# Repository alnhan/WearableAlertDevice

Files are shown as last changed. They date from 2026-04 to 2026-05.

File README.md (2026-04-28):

# Senior Capstone Project: Wearable Alert Device
University of Oklahoma

School of Electrical and Computer Engineering

Semester: Spring 2026

<ins>Team Members:<ins>

Project Manager - Jonas Wollman

Hardware Engineer - Ryan Kiesau

Hardware Engineer - Cody Chan

Software Engineer - Alex Ho

README written by Alex Ho

# Overview
This repository contains all project files pertaining to the Wearable Alert Device project. The following information
provides guidance for setting up the software development environment as well as a general description of each
of the major components of the software.

# Table of Contents
1. [Downloading Arduino IDE](#downloading-arduino-ide)
2. [Initial Environment Setup](#initial-environment-setup)
   - [Arduino Nano ESP32 Board Package Installation](#arduino-nano-esp32-board-package-installation)
   - [Pin Numbering Setting Configuration](#pin-numbering-setting-configuration)
   - [Required Library Dependencies](#required-library-dependencies)
   - [Verifying and Uploading Code to a Microcontroller](#verifying-and-uploading-code-to-a-microcontroller)
4. [Software Development](#software-development)
   - [WearableAlertDevice.ino](#wearablealertdeviceino)
   - [config.h](#configh)
   - [WirelessDataTransmission.h/.cpp](#wirelessdatatransmissionhcpp)
   - [GunshotDetection.h/.cpp](#gunshotdetectionhcpp)

# Downloading Arduino IDE
For this Capstone project, the Arduino IDE was used as the software development environment.
The Arduino IDE can be downloaded [here](https://www.arduino.cc/en/software/). Ensure that 
some version of Arduino IDE 2.0 is downloaded, not the legacy Arduino IDE 1.0. 

Back to [Table of Contents](#table-of-contents)

# Initial Environment Setup
Once the Arduino IDE has been installed, some initial setup in its environment is needed before code can be correctly
uploaded into the Arduino Nano ESP32 microcontroller. There are three important parts to the setup: installing the Arduino
Nano ESP32 board package, setting the pin numbering to GPIO numbers, and installing library dependencies. 

Back to [Table of Contents](#table-of-contents)

## Arduino Nano ESP32 Board Package Installation
The first stage of the environment setup is installing the proper board package so that the environment can correctly compile
code and upload programs for Arduino Nano ESP32 microcontrollers. In the Arduino IDE, look on the left for the Boards Manager 
tab. Click on the Boards Manager tab to open it up.

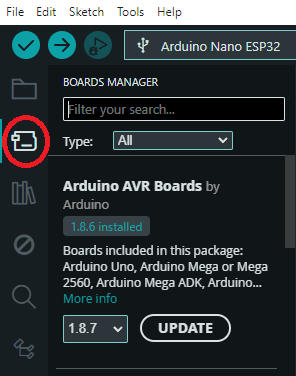
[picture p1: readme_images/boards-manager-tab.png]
Screenshot of Boards Manager tab in the Arduino IDE (circled in red).


Figure 1: Screenshot of Boards Manager tab in the Arduino IDE (circled in red).

In the search bar, type "Arduino ESP32 Boards." This package will contain the settings to recognize Arduino Nano ESP32
hardware. Select the Install button if the package is not already installed.

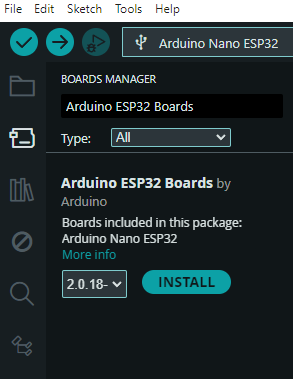
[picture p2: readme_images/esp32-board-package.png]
Screenshot of the Arduino ESP32 Boards package not installed yet.


Figure 2: Screenshot of the Arduino ESP32 Boards package not installed yet.

Once the package has been installed, the Arduino IDE will automatically install all the common software libraries associated with 
ESP32 microcontrollers, such as WiFi, Bluetooth, etc. No additional steps are needed to install these libraries.

Back to [Table of Contents](#table-of-contents)

## Pin Numbering Setting Configuration
The software developed for this project has been written specifically to use the Arduino Nano ESP32's GPIO numbers, not the 
standard Arduino pin numbers that are labeled on the physical device. **NOTE: IF THE PIN NUMBERING IS SET TO ARDUINO PIN NUMBERS 
INSTEAD OF GPIO NUMBERS, THERE WILL BE A GOOD CHANCE THAT INCORRECT PINS ON THE MICROCONTROLLER WILL BE USED BY THE SOFTWARE,
WHICH WILL MOST LIKELY PREVENT THE HARDWARE FROM FUNCTIONING PROPERLY.**

To change the pin numbering setting in the Arduino IDE, navigate to `Tools >> Pin Numbering` at the ribbon near the top of the IDE. 
In the `Pin Numbering` setting, there will be two options: `By Arduino pin (default)` and `By GPIO number (legacy)`. Set the `Pin Numbering`
setting to the `By GPIO number (legacy)` option.

Pin Numbering setting

Figure 3: Screenshot of Pin Numbering setting being set to the "By GPIO number (legacy)" option. The Pin Numbering setting can be 
found in the Tools tab in the ribbon near the top of the IDE.

Back to [Table of Contents](#table-of-contents)

## Required Library Dependencies
There are a few open-source libraries that the software relies on for its functionality. These external libraries are not automatically
installed by the Arduino IDE and will have to be installed manually. Below is a list of the open-source libraries:

1. [DFRobot_GNSS](https://github.com/DFRobot/DFRobot_GNSS) by DFRobot
2. [arduinoFFT](https://github.com/kosme/arduinoFFT) by kosme

The libraries can be downloaded by using the GitHub links above, or they can also be found in the `Software/dependencies` folder for
this project.

Once these libraries are downloaded, they need to be installed manually into the Arduino IDE. Navigate to `Sketch >> Include Library >> 
Add .ZIP Library...` at the ribbon near the top of the IDE. After clicking the `Add .ZIP Library` option, find the local `.zip` files 
of the libraries and add them to the Arduino IDE. 

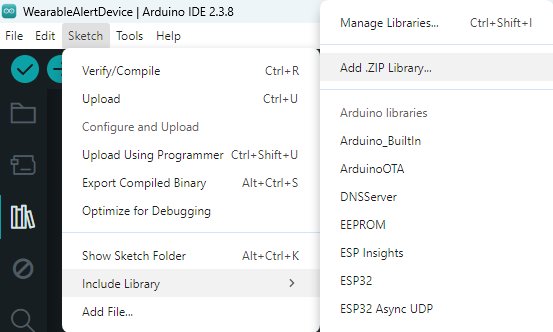
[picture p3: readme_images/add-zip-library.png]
Add .ZIP Library


Figure 4: Screenshot of the navigation to the "Add .ZIP Library..." option in the Arduino IDE.

Back to [Table of Contents](#table-of-contents)

## Verifying and Uploading Code to a Microcontroller
When connecting an Arduino Nano ESP32 microcontroller to the computer for the first time, it is possible that the Arduino IDE does not
recognize the hardware as an Arduino Nano ESP32 model specifically. Before verifying or uploading code to the microcontroller, first
navigate to `Tools >> Board`. Ensure that the board type says "Arduino Nano ESP32." If the board type does not say that, set the board
type to "Arduino Nano ESP32" by navigating to `Tools >> Board >> Arduino ESP32 Boards` and selecting "Arduino Nano ESP32."

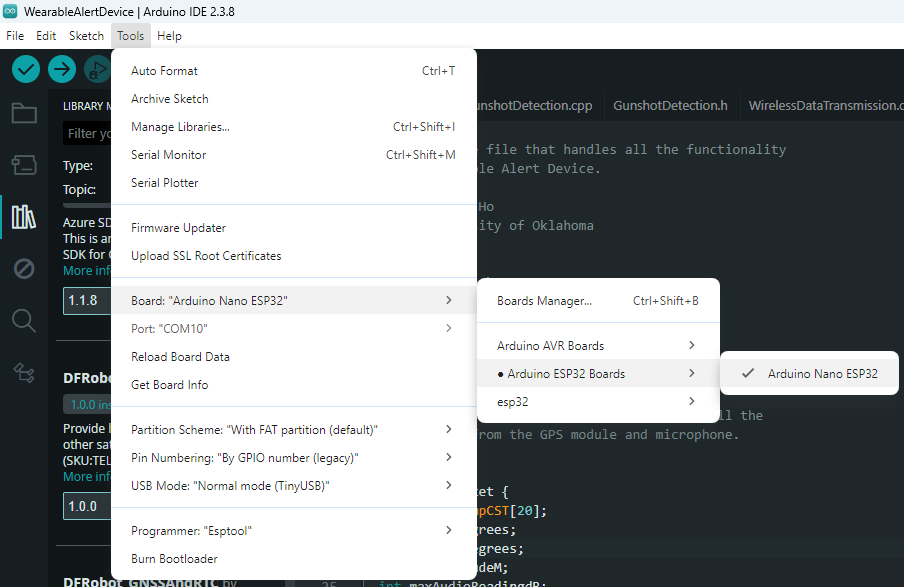
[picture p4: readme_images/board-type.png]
Selecting Board Type


Figure 5: Screenshot of the IDE's board type being set to "Arduino Nano ESP32."

To verify that the Arduino IDE properly recognizes the microcontroller as an Arduino Nano ESP32, connect the microcontroller to the
computer's USB-A port, and the IDE should display the COM port number and "Arduino Nano ESP32."

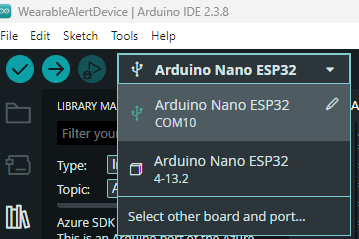
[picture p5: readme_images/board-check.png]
Checking Board Type


Figure 6: Example screenshot of the IDE detecting an Arduino Nano ESP32 on COM Port 10.

Once the IDE properly recognizes the Arduino Nano ESP32, code can now be properly installed on the hardware. There are two important
buttons in the IDE for installing software onto the microcontroller: the `Verify` button and `Upload` button. 

Verify and Upload Buttons

Figure 7: Screenshot of the `Verify` button (circled in red) and `Upload` button (circled in green) in the Arduino IDE.

The `Verify` button, identified by a checkmark symbol, compiles the code and ensures there are no compile errors. This button does not
upload the software into the microcontroller. The `Upload` button, identified by an arrow pointing right, performs the same function as 
the `Verify` button. However, once the code has been successfully compiled, the `Upload` button will then upload the software to the 
connected microcontroller. **For best practices, it is best to first press the `Verify` button before pressing `Upload` button when 
uploading new code to the microcontroller.**

# Software Development
The following section provides a general description of each of the software files. If further details are needed, comments and 
documentation can be found within the software files themselves. 

Back to [Table of Contents](#table-of-contents)

## WearableAlertDevice.ino
`WearableAlertDevice.ino` is the main software file for this project. This file serves as the device's main source for functionality.
The Arduino Nano ESP32 will look to this file for how to control the connected hardware. Functions and variables from supporting files 
such as `config.h`, `WirelessDataTransmission.h`, and `GunshotDetection.h` can also be used by `WearableAlertDevice.ino`. 

Back to [Table of Contents](#table-of-contents)

## config.h
`config.h` contains all the adjustable settings for the Wearable Alert Device. Instead of going into each of the different software
files to change certain settings, which can introduce potential bugs if not carefully done, these settings can be changed directly 
in `config.h`, and those changes will automatically propagate throughout the rest of software. As a result, changing a specific setting
for the Wearable Alert Device only requires changing a single value in `config.h`, and developers do not need to parse through all the
complex code to change each instance of the setting that appears in the code.

Back to [Table of Contents](#table-of-contents)

## WirelessDataTransmission.h/.cpp
`WirelessDataTransmission.h` handles the software that wirelessly transmits the data from the Wearable Alert Device to a mobile app.
For this project, Bluetooth Low-Energy was used as the protocol for transmitting data wirelessly. Thus, `WirelessDataTransmission.h`
contains the software that initializes the microcontroller's Bluetooth Low-Energy module and handles when a mobile device connects
or disconnects from the Wearable Alert Device. 

Back to [Table of Contents](#table-of-contents)

## GunshotDetection.h/.cpp
`GunshotDetection.h` handles the audio sampling and processing needed to detect a gunshot. This file creates all the necessary
buffers that store audio samples collected by the microphone. In addition, the file also performs the mathematical conversions
needed to convert the analog voltage from the microphone into a fairly accurate dB Sound Pressure Level reading. What is 
important to note about `GunshotDetection.h` is that it includes the previously-mentioned `arduinoFFT` library, allowing 
`WearableAlertDevice.ino` to use `arduinoFFT`'s frequency conversion and analysis functions. 

Back to [Table of Contents](#table-of-contents)

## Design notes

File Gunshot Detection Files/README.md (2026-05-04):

# Microphone Information
Microphone files for the OU Capstone Wearable Alert Device project. <br>
Schematics and Datasheets

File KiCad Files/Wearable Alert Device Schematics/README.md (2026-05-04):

# Contains all schematics related to the whole Wearable Alert Device
Both the GPS feature and the microphone feature are included in the schematics.

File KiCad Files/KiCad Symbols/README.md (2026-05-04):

# Kiad Symbols related to the Wearable Alert Device

CCEW Wearable Alert Device: All symbols related to the Gunshot Detection
Arduino Nano ESP32, I2S MEMS Microphone, Boost Converter, and Button

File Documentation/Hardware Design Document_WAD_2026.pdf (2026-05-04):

## Wearable Alert Device: Hardware Design Document

University of Oklahoma
School of Electrical and Computer Engineering Spring 2026 Semester
Senior Capstone Project

Team Members:
Jonas Wollman - Project Manager Ryan Kiesau - Hardware Engineer Cody Chan - Hardware Engineer Alex Ho - Software Engineer

Written By:
Cody Chan
Ryan Kiesau

## Table of Contents

Overview | 2
Power Supply | 3
Micro-Lipo Charger | 4
Position Module | 5
Analog Microphone | 6
Arduino Nano Esp32 | 7
Testing LED | 8
Boost Converter | 9
Hardware Documentation | 11
Block Diagram | 11
Schematics | 13

Overview
This hardware design document describes the various hardware components used in the

building and testing of the CCEW WAD capstone project. This document will list all hardware

developments including listings on all parts/chips used in the design of the WAD, Block

diagrams of the WAD, Schematics of the WAD, and the final PCB design that was not

implemented but planned for.

The WAD’s mission is to create a discrete device that could be worn in case of

emergency assistance. The overall goal of the WAD is to alert authorities on location, elevation,

and an immediate threat such as a gunshot.

The intended audience that we are building the device for is not that of first responders.

Instead we are thinking about secondary responders who may not have field training but may

still be in dangerous scenarios while working. This device is made for them to have a way of

contacting authorities while not giving too much information to the potential assailant.

Power Supply

Description:

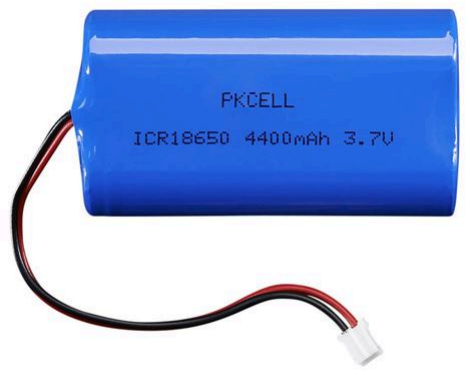
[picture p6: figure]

A lithium-ion battery pack made of two 2200mAh cells totaling to 4400mAh operating at 3.7V

Specifications:
Parameters: | Values
Lithium-ion Cells | 2 x 2200mAh
Max Recommended Charging Rate | 1A
Max Recommended Discharging Rate | 2.2A

Role in this system:

This battery pack is the main source of power for the device. Connected with a JST 2-pin cable, the pack is compatible with any JST or similar connector.

Why was this component chosen:

This battery pack was chosen as it provides more than enough amperage to cover all components operating within the device. Its milliampere-hours can power the device for an extended amount of time before needing to recharge. This battery pack is also compatible with the device’s chosen charging component while non-Adafruit batteries are not.

Micro-Lipo Charger

Description:

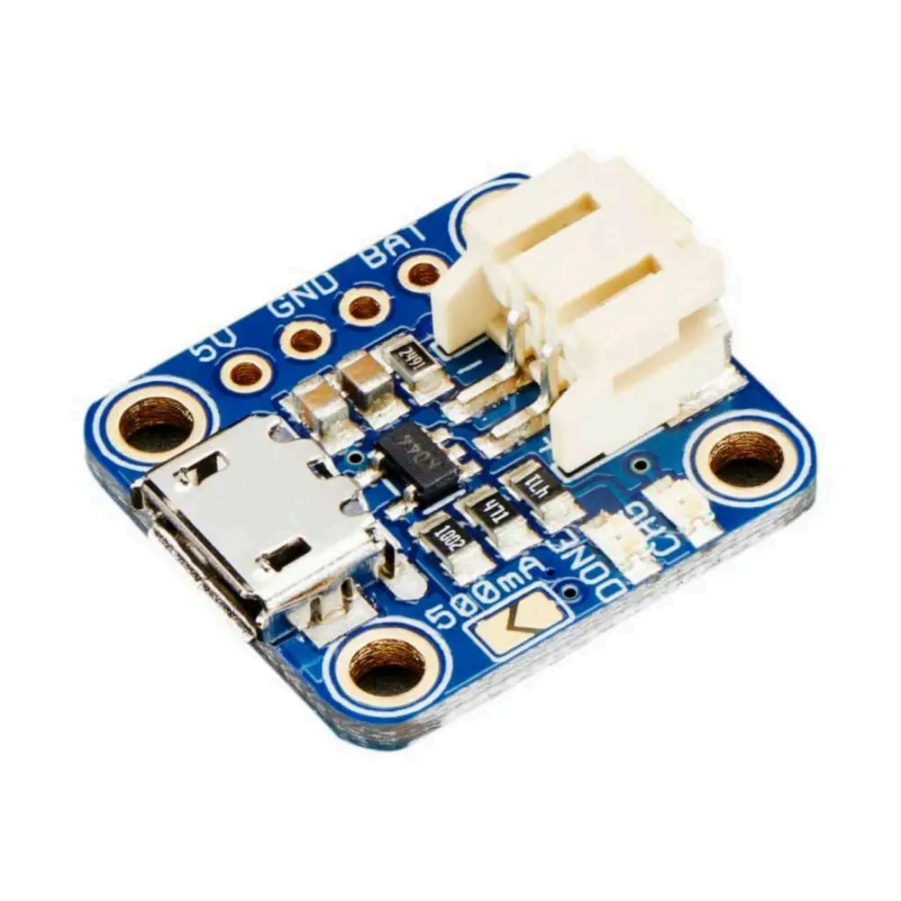
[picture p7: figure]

A small Lipo charger able to recharge any 3.7/4.2V lithium polymer or lithium ion rechargeable battery by a JST plug through a Micro-B USB. A red LED will be active when charging and a green LED will be active once charging is complete.

Specifications:
Parameters: | Values
Recommended Batteries | Rechargeable 3.7/4.2V LiPoly/LiIon Batteries (Adafruit Only)
Micro-B USB Connector Voltage | 5V
Charge Current | 100mA, Adjustable to 500mA

Role in this system:

The Lipo-Charger regulates the charging process using a constant current, prevents overcharging, and protects the battery. Due to the dual functionality of the USB and JST ports, it allows the device to be recharged without disconnecting the battery, offering continuous operation and usability.

Why this component was chosen:

The Micro-Lipo Charger was chosen mainly for its compatibility with the battery pack. It allows the user to be able to charge the device without needing to disconnect the battery. The charger also handles all battery protection independently of the microcontroller without external components, improving safety and reliability. Additionally, the charge current can be changed between 100mA and 500mA or be fully customizable with a single resistor on the PROG pin

Position Module

Description:

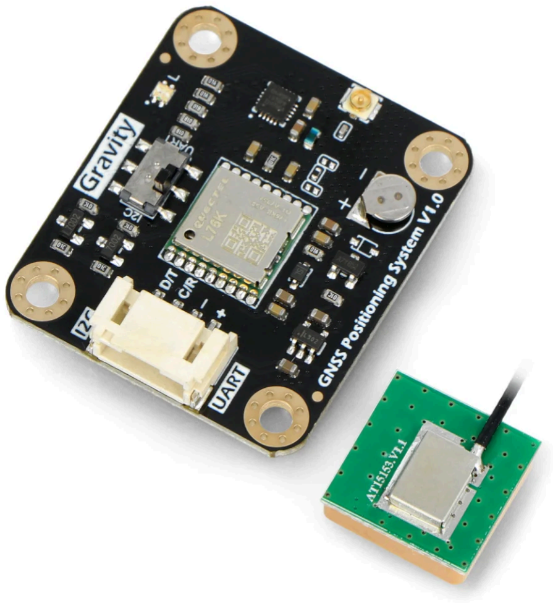
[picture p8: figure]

The Gravity: Receiver Module is a joint positioning mutli-satellite device that provides high-precision, high-speed, and stable data readings of longitude, latitude, altitude, and time.

Specifications:
Parameters: | Values
Operating Voltage | 3.3-5.5V DC
Output Signal | I2C/UART
Power Consumption | 40mA
Positioning Time | 30s-Cold Start; 2s-Hot Start
Antenna Interface | IPEX1
Antenna Frequency | 1561-1575.42MHz +/- 3MHz

Role in this system:

The receiver module is responsible for determining the device’s real-time geographical location. It receives signals from multiple satellite constellations and computes position data. This information is sent to the microcontroller where it’s constantly updated until an alert is activated and sends out the most recent data to the app for emergency services.

Why this component was chosen:

This module was chosen because it supports multiple satellite constellations, which improves accuracy and reliability in multiple environments. The module offers two-meter accuracy and quick positioning updates, which is critical for emergency response applications. Altitude is given alongside time and coordinates, which some smartphone maps do not offer or have the information split between different apps. Additionally, the module supports I2C, allowing for simple integration for the microcontroller and reduces wire complexity.

Analog Microphone

Description:

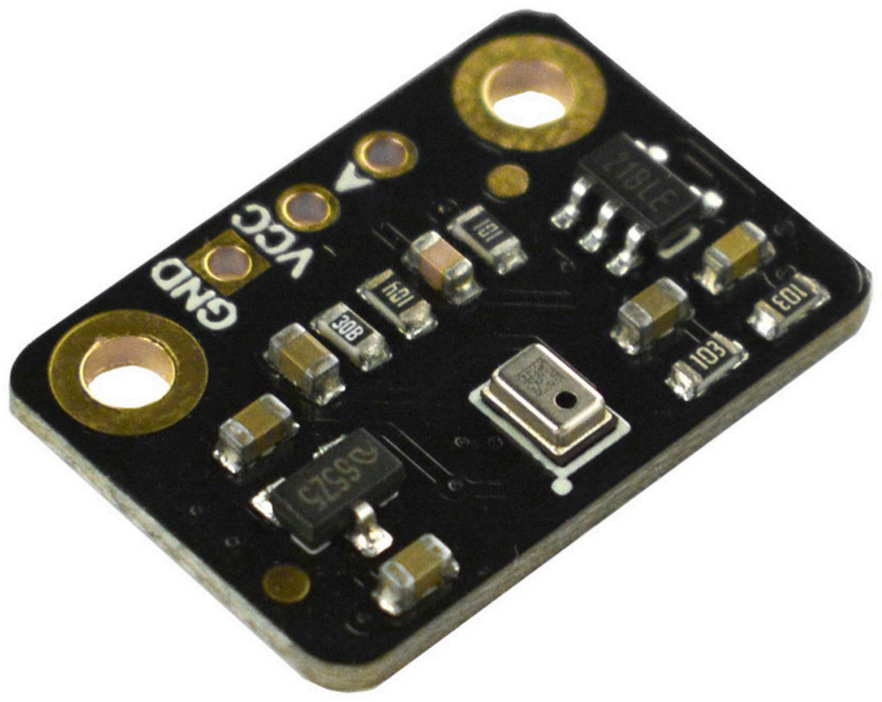
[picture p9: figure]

The Fermion MEMS Microphone is an compact analog microphone built on a Micro-Electro-Mechanical System (MEMS).

Specifications:

Parameters: | Values
Operating Voltage | 3.3V DC
Direction | Omnidirectional
Output Type | Analog
Maximum Sound Pressure Level | 110 dB
Signal to Noise Ratio | 59 dB

Role in this system:

This microphone is the main source where soundwaves are read and analyzed. It constantly monitors the environment and produces an analog voltage that will be sent via the amplitude of incoming sounds. This signal will be converted and passed through an ADC GPIO pin on the Arduino Nano ESP32, where it is sampled in the software. This microphone does not perform any type of action or decision-making on its own. The microphone’s purpose is to read in the data for the software to read and interpret. In this case, it will read in any type of noise, ranging from “quiet” to a gunshot.

Why this component chosen:

The Fermion MEMS Microphone was chosen based on a misordering issue. Originally, the plan was to use the Fermion I2S MEMS Microphone, which is a digital microphone able to read up to 140 dB. However, there was an ordering issue, and the wrong component came in. The digital microphone would have been using I2S and would have reduced a lot of unnecessary noise; however, the Fermion MEMS Microphone still functions as needed. The MEMS Microphone is directly connected to the ESP32’s ADC and has no protocol, meaning no clock or synchronization is needed, making the firmware simpler. The max 110 dB also allows the device to read in all types of loud sounds without damaging the microphone sensors, even if clipping were to occur.

Wiring to the Arduino Nano ESP32:

VCC | 3.3V
GND | GND | Shared GND for Device
Aout | DC GPIO Pin | Analog Audio

A 0.1 uF decoupling capacitor should be placed between the VCC and GND pins of the microphone. This filters out the noise the analog microphone produces before audio sampling.

Arduino Nano Esp32

Description:

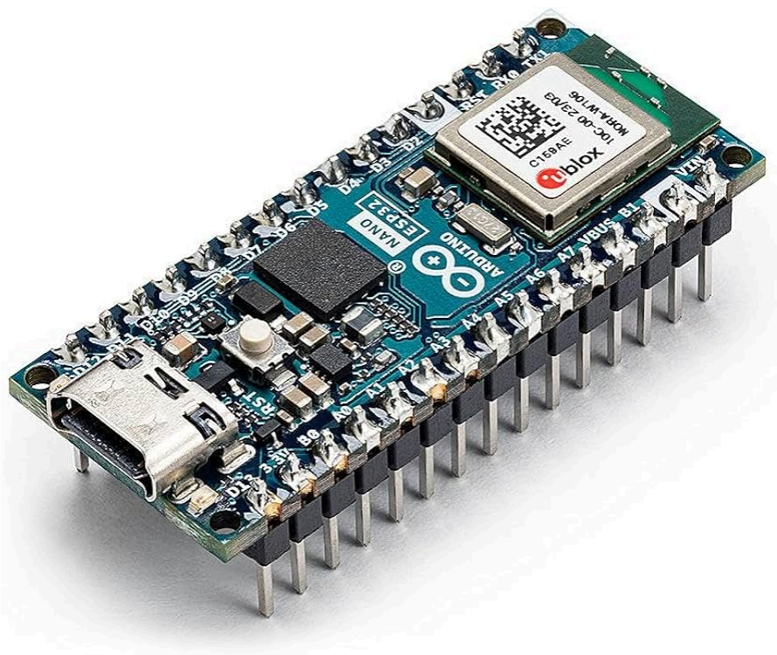
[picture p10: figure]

The Arduino Nano ESP32 is built around the r-block NORA-W106 module that has capabilities of Wi-Fi and Bluetooth 5.0 functions in a small form factor. This microprocessor will be considered as the brain that will collect the audio from the microphone, run through the firmware, collect GPS data, and transmit an emergency response via Bluetooth. This Arduino

Nano ESP32 can be powered by a USB-C built on the board but this product will be powered by a 3.7V Li-ion battery, running on an operating voltage of 3.3V.

Specifications:

Parameters: | Values
Operating Voltage | 3.3V
Bluetooth | Bluetooth 5.0 (Blue Energy)
GPIO | Multiple digital and analog I/O pins
Form | Arduino Nano

Role in the System:

The Arduino Nano ESP32 will serve as the brain of the gunshot-detection and GPS module. When working with the microphone, it will continuously sample voltage data from the microphone output at a defined sampling rate. Each sample will be stored for processing. There will be a Hamming window and the Fast Fourier Transform that will be during this analysis. When the characteristics are met (the threshold), the firmware will send a signal in the event of a gunshot and trigger an alert response. For the button, it will be connected to a GPIO pin to act as an emergency button, regardless of the microphone detection. Upon detection or a button press, the ESP32 will send a signal via Bluetooth to alert responders. The LED connected to the GPIO pin is for testing purposes only, and whenever a detection happens or a button is pressed, it will send a visual instead of looking at the phone.

Why was this component chosen:

The Arduino Nano ESP32 was chosen because it had all the features needed for our product to function. It was sufficient enough to perform Bluetooth communication, processing, and hardware integration.

Testing LED
Description:

The testing LED is a standard red LED used for development and validation assistance. The LED is also used to turn on if there is a gunshot detected or if the button is pressed to signal to the user discreetly that a signal has been sent. This LED will be incorporated into the final product, but it will not be a part of the interface for the user to use. For this product, it is made to be as discreet as possible, so having an LED turn on in the field would potentially alert the perpetrators.

Specifications:

Parameters: | Values
Type | Red LED
Forward Voltage | ~2.0V – 3.3V LED (2V for Red)
Current Limiting Resistor | 1k Ohm
Control Type | Digital GPIO Pin

Role in the System:

The LED is connected to the GPIO output on the Arduino Nano ESP32. In the firmware, whenever a gunshot is detected or if the button is pressed, it will send an alert via Bluetooth to the phone to send a signal. During the testing phase, like loud clapping and gunshot, the LED turns on. This allows us to know whether a signal was sent or not and to validate the performance without waiting for the notification on a phone.

Connections:

LED Anode (+) | To a resistor, current limiting, to GPIO Pin
LED Cathode (-) | Directly to GND

Boost Converter

Description:

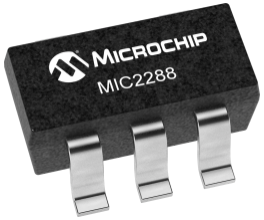
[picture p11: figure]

The MIC2288 is a 1.2MHz PWM, DC/DC boost switching regulator. It implements a constant frequency current-control scheme designed for high-efficiency power conversion.

Specifications:
Parameters: | Values
Input Voltage | 2.5-10V
Output Voltage | Adjustable to 34V
PWM Operation | 1.2MHz
Switch Current | Over 1A

Role in the system:

The MIC2288 Boost Converter steps up the battery voltage from 3.7V to 5V required by the microcontroller. It provides a stable supply voltage to the microcontroller, even as the battery voltage drops during discharge.

Why this component was chosen:

The MIC2288 was chosen as it’s a compact and efficient boost converter that requires few external components, making it ideal for tight-spaced designs. It can provide a 5V output from a low-voltage battery while maintaining efficiency, maximizing battery life. Since the component is adjustable to 34V, this makes it easy to modify if the output voltage needs to be changed.

NOTE: The MIC2288 is not included within the final design of the device nor the schematic. Multiple voltages and external component values were tested, but the output voltage ripple was too much for the Arduino Nano ESP32 to handle such that the Bluetooth feature was not operational. Luckily, the entire device works perfectly when powered directly from the 3.7V battery into the microcontroller’s VIN pin.

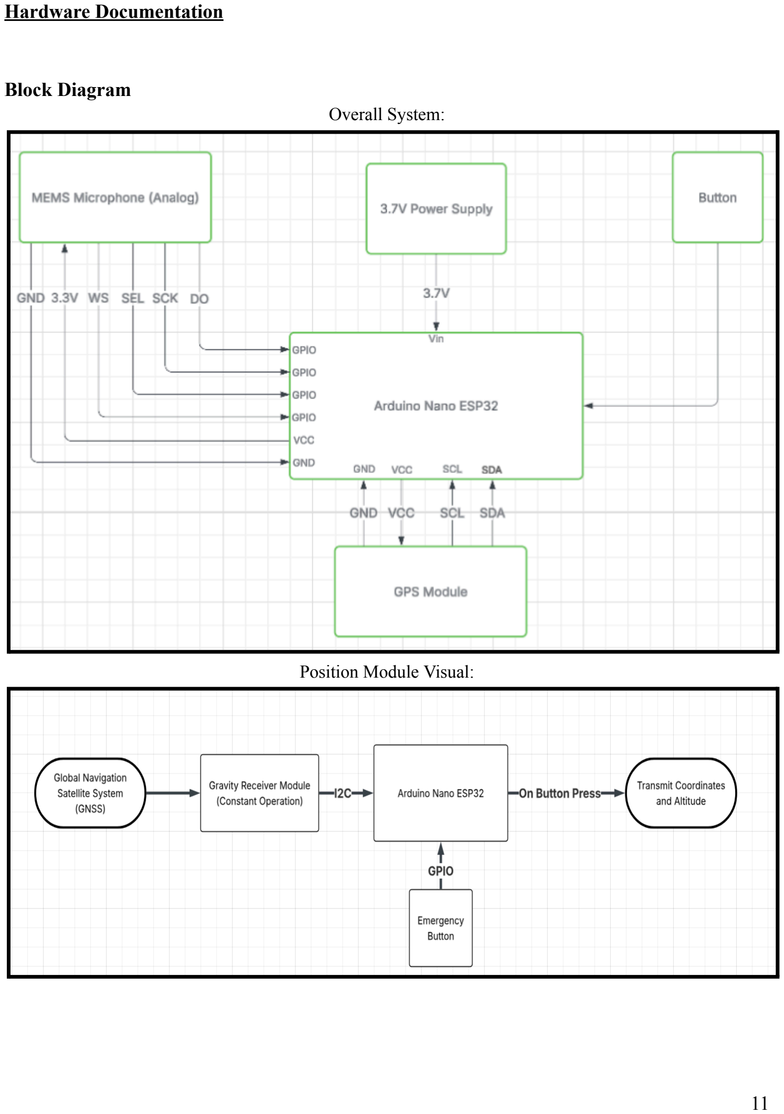
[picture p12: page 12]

Hardware Documentation

Block Diagram
Overall System:

Position Module Visual:

Microphone Visual:

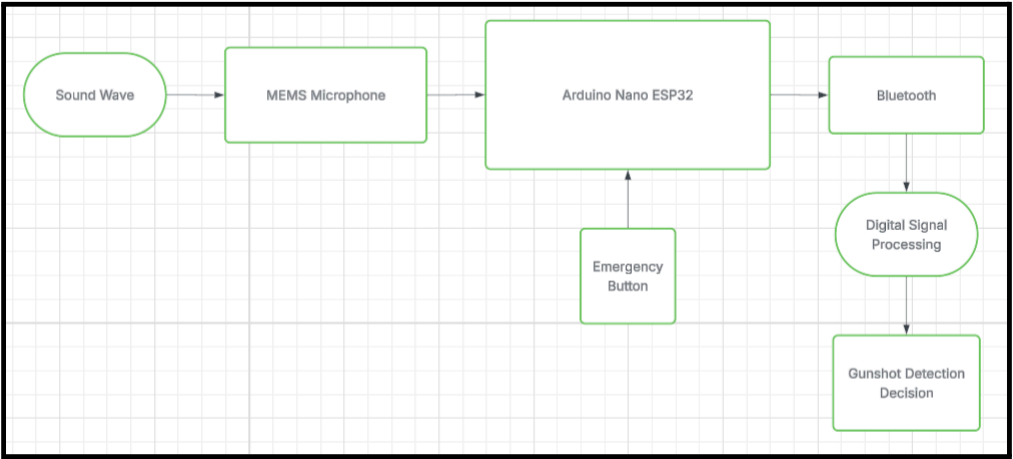
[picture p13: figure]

Schematics

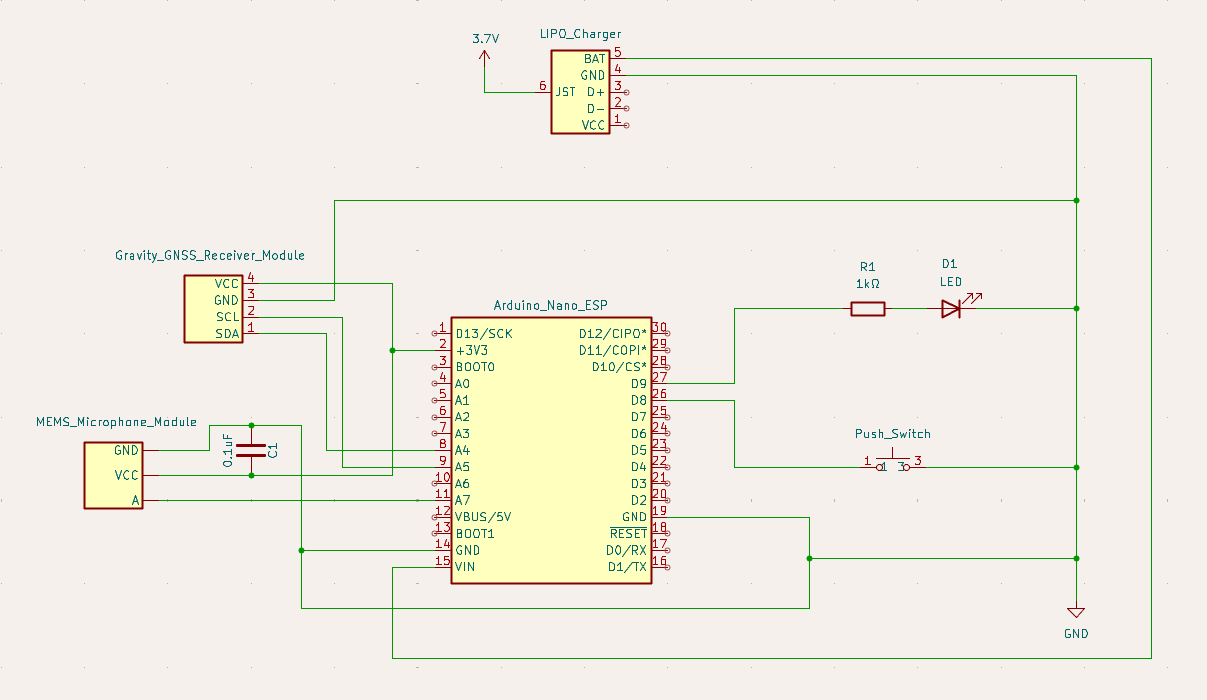
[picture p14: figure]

Starting with the microphone, the VCC is connected to the 3.3V rail of the Arduino Nano ESP32. The analog pin of the microphone is connected to pin A7 of the ESP32. Between the GND and the VCC of the microphone, there is a decoupling capacitor of 0.1uF to limit the noise from the analog microphone. Next with the Gravity: GNSS Receiver Module (GPS Module), the VCC is connected to the same 3.3V rail of the ESP32, the SCL is connected to A5 of the ESP32 because the pin has SCL capabilities, and the SDA is connected to A4 of the ESP32 because the pin has SDA capabilities. The 3.7V is connected to the Micro Lipo Charger via a JST connector and then the Micro-Lipo Charger’s BAT is connected to the Vin of the ESP32. The testing LED’s anode is connected to a limiting resistor to pin D9 of the ESP32 and the cathode is connected to GND. The push switch pin 1 is connected to pin D8 of the ESP32 and pin 3 of the push button is connected to GND. All GND from all the components in this circuit connects to the common GND.

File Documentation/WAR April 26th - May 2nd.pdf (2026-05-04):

Executive Summary: For our last week the team finished everything. Our documentation on

both the hardware and software side has been completed and the additional documentation has

been completed and committed to the github. This week we also finished our Final demo

presentation and practiced it multiple times in order to get a better understanding for our final

presentation in person on Monday 5/4. The team also created a case for the WAD and although

they ran into issues with the initial design they were able to get a working usable case on the

WAD. Our team is ready and waiting to give our final presentation at which point all

documentation will be handed over in the form of the presentation folders and the USB archives.

Task / Time Take / Completed Y/N
Hardware:

Cody C.
Progress:
- 4/26 –
- Work on Presentation Slides (~1 Hours)

■ Changes made to the project:

■ I2S Microphone to MEMS Microphone

■ Everything is the same, omnidirectional, 59dB Noise to

sound ratio

■ Main difference is the Sound Pressure Level (140dB vs

110dB)

■ Future Planning:

■ Smaller form factor

■ PCB implementation

■ High Decibel Microphone

- Calculated Run time for Wearable Alert Device
- Edit GitHub (~20 Minutes)
- 4/29 –
- Team meeting (~2 Hours 30 Minutes)

■ Field data collection for GPS module

■ Talk about plans for Final Demonstration

■ Practiced Final Presentation

- Update Symbol for Micro-Lipo Charger (~5 Minutes)
- Update Schematics and Wiring Diagram (~5 Minutes)
- Work on Hardware Design Document (~3 Hours)

■ Create descriptions for Arduino Nano ESP32, LED, and MEMS

Microphone

■ Upload Schematics

■ Upload Block Diagrams

■ Visual of Microphone

■ Whole Black Diagram

- Update GitHub (~10 Minutes)
- 5/2 –
- Team Practice (~30 Minutes)

Total Hours Worked: ~ 7 Hours 40 Minutes

Future Work/Plan

- 5/4 - Final Demonstration at 5:30 pm

Task / Time Take / Completed Y/N
Hardware:

Ryan K.
Progress:
- 4/27 - Presentation Slides (~1hr 30min)
- Worked on our Final Demo Presentation Slides for the upcoming team meeting
- 4/29 - Team Meeting/Presentation Practice (~2hr 30min)
- Met with team to talk about upcoming needs with documentation
- Gathered GPS data and made final edits to Final Demo Slides
- Practiced the Final Demo with the team
- 4/29 - Documentation (~1hr 45min)
- Started writing the Hardware Design Document

■ Filled out and gathered information for the battery and Micro-Lipo

Charger

- 5/1 - Documentation (~1hr 30min)
- Continued filling out the Hardware Design Document

■ Filled out and gathered information for the positioning module, and the

boost converter

- 5/2 - Finalize Documentation (~20min)
- Formatted and reviewed the Hardware Design Document and made minor edits

where needed

Total Hours Worked: ~7hr 35min

Future Work/Plan:

- Present our Final Demo on 5/4 @ 5:20pm

Task / Time Take / Completed Y/N
Software:

Alex H.
Progress:
- 4/27 (3 h 52 min)
- Created two gunshot detection videos for the Final Demo presentation, showing

off results.

- Computed accuracy of WAD for each gunshot detection video.
- Shared video format with the team to receive their approval and feedback.
- Inserted gunshot detection videos into the Final Demo presentation.
- 4/28 (1 h 41 min)
- Formatted appendix and gunshot detection slides for the Final Demo presentation.
- 4/29 (2 h 21 min)
- Worked with the team to obtain some new GPS tracking data to present at the

Final Demo.

- Obtained coordinates and altitude of the OU Engineering Quad fountain.

Compared this data from the WAD with data from Google Maps and an

altitude app.

- Practiced Final Demo presentation with the team.
- 5/1 ( 5 h 37 min)

- Finished the user manual for the Wearable Alert Device. Added images and steps

for installing the nRF Connect app, as well as writing brief descriptions of each of

the device’s features.

- 5/2 (39 min)
- Ran more practices with the team on the Final Demo presentation.
- Discussed plans to merge the GitHub repository so that all project files are

together.

- Added slight modifications to the Final Demo presentation.
- 5/3 (44 min)
- Double-checked that the README file, user manual, and code are all uploaded to

the GitHub repository in their final versions.

- Merged all branches in the GitHub repository to compile all project files together.

Total Hours Worked: 14 h 54 min

Future Work/Plan:

- Present project at the Final Demo presentation on Monday 5/4

Project Manager:

Jonas W.
Progress:
- 4/28 Finish my portion of final slides (1 Hours)
- Create and finish my final budget slides and introduction slide
- 4/29 Team meeting (~2 Hours 30 Minutes)
- Test the Position Module
- Test the bluetooth range

- 4/30 Create the WAD Case (3 Hours)
- Create the STL and Obj Files of the WAD Device’s case
- Upload to the GIT
- 5/1 Send the Case to volunteer 3D printer (1 Hours)
- Coordinate with the volunteer on the printing of the Case
- Plan on pick up/drop off of case
- 5/3 Finish Documentation(2 Hours)
- Finished the Final budget/BOM
- Finished formatting of the HDD and the User Manual
- Upload everything to GitHub
- 5/3 Build Case (1 Hours)
- Got the case parts and finished assembling, ran into the issue of the device on the

inside being a bit too long but we found a solution by adding lots of tape.

Total Hours Worked: 10 Hours 30 Minutes

Future Work/Plan:

Print and create the final demo folders

Format the USB archives

Present the final Demo!

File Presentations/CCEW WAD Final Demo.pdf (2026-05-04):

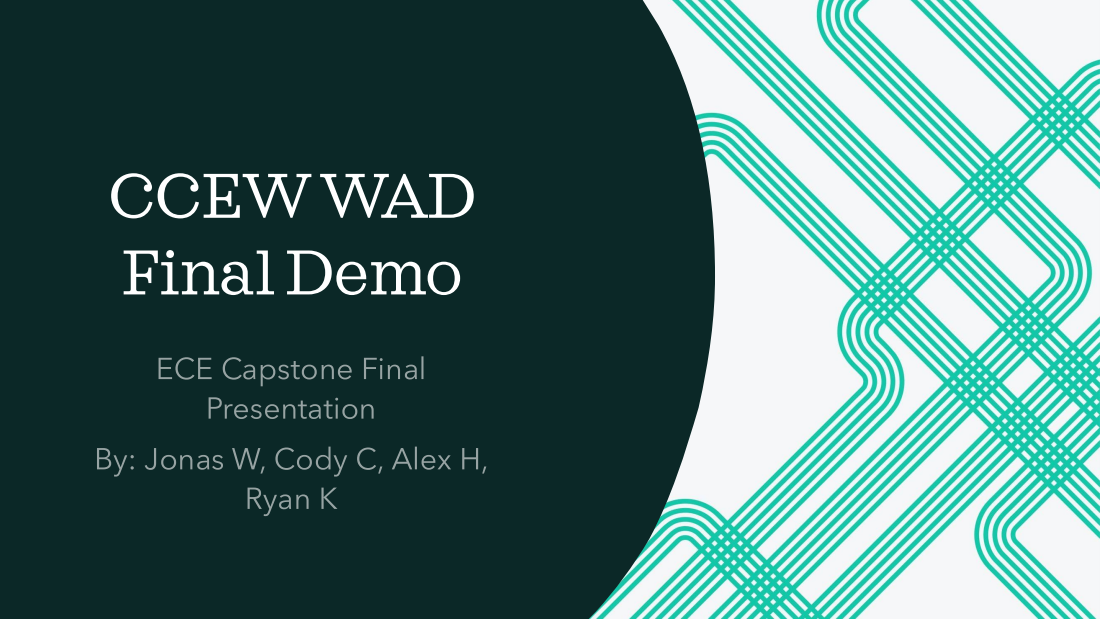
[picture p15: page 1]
CCEW WAD Final Demo

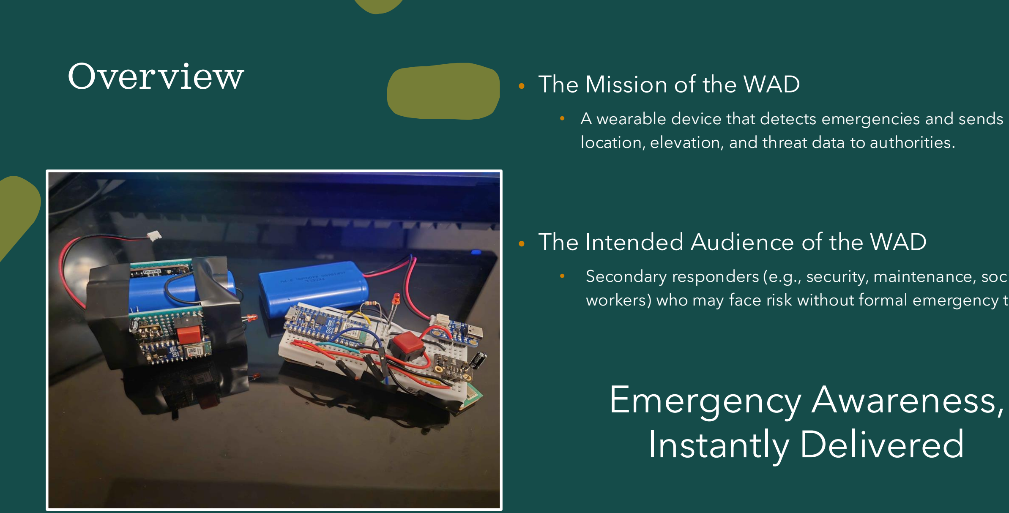
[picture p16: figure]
Overview; • The Mission of the WAD; • The Intended Audience of the WAD; Emergency Awareness, Instantly Delivered

- A wearable device that detects emergencies and sends real-time location, elevation, and threat data to authorities.
- Secondary responders (e.g., security, maintenance, social workers) who may face risk without formal emergency training.

JW

# Specific Features

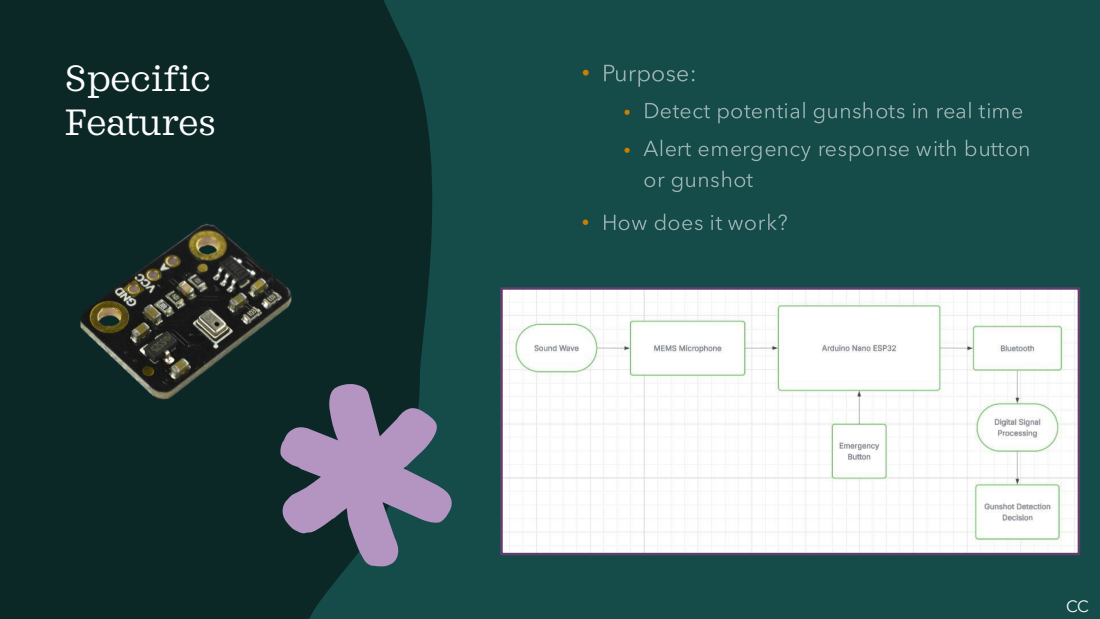
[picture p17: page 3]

# Specific Features Con't

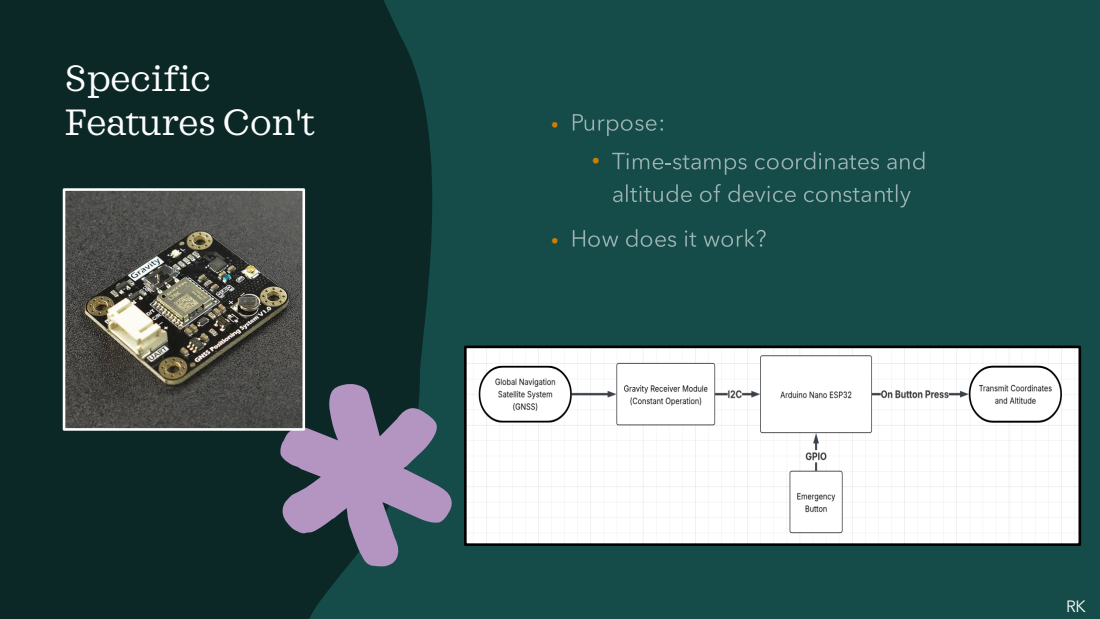
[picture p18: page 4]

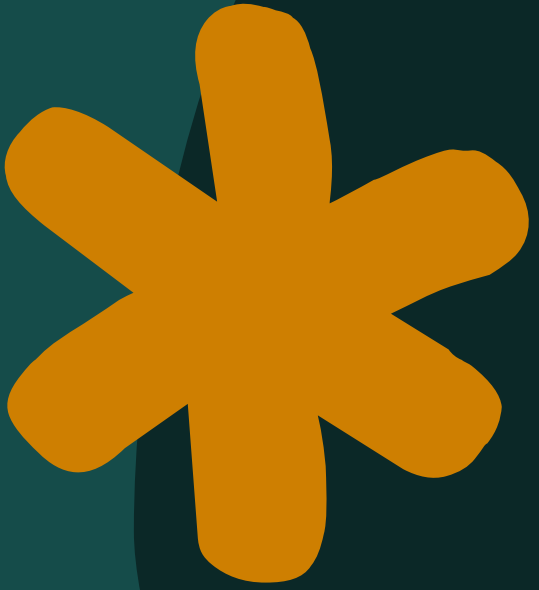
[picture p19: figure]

# Changes Made in Project

CC/
RK

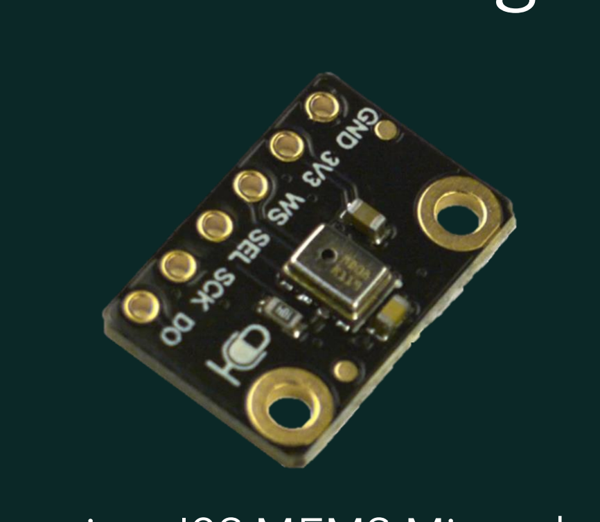
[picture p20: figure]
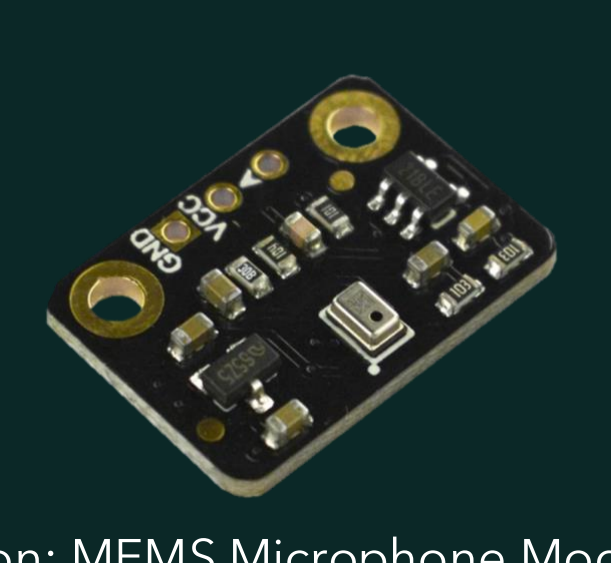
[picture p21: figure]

Fermion: I2S MEMS Microphone | Fermion: MEMS Microphone Module

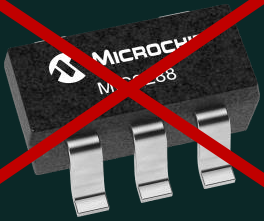
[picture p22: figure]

## Testing and Demonstration: Button and Wireless Data Transmission

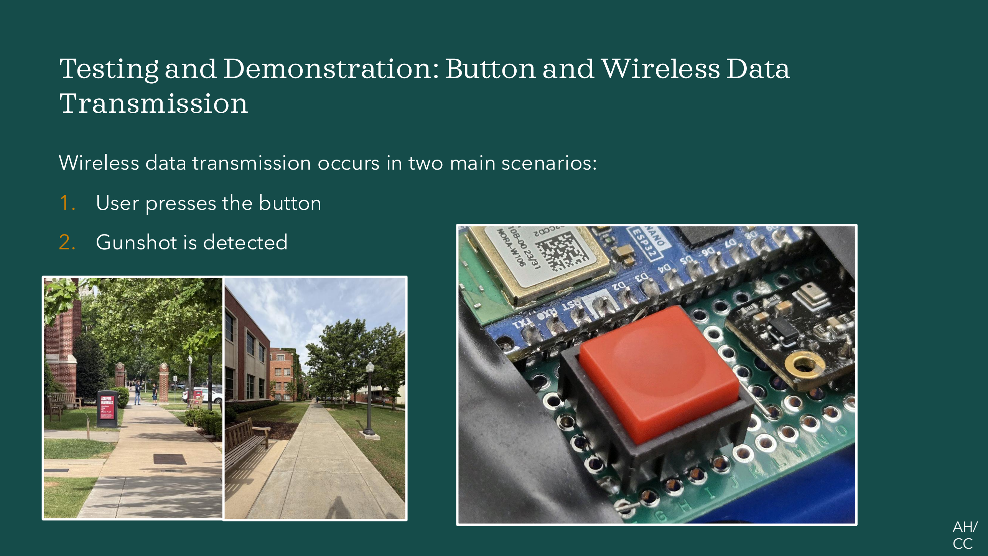
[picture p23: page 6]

Wireless data transmission occurs in two main scenarios:

1. User presses the button
2. Gunshot is detected

AH/
CC

## Testing and Demonstration: GPS Module

AH/
RK

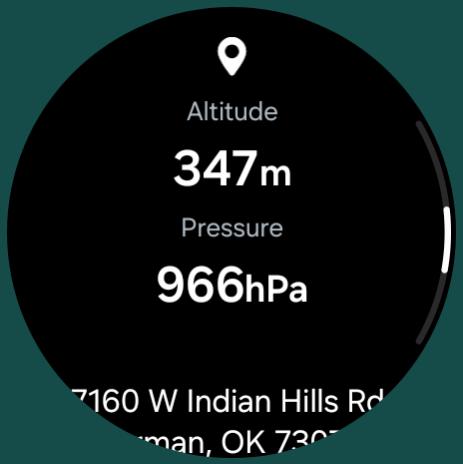
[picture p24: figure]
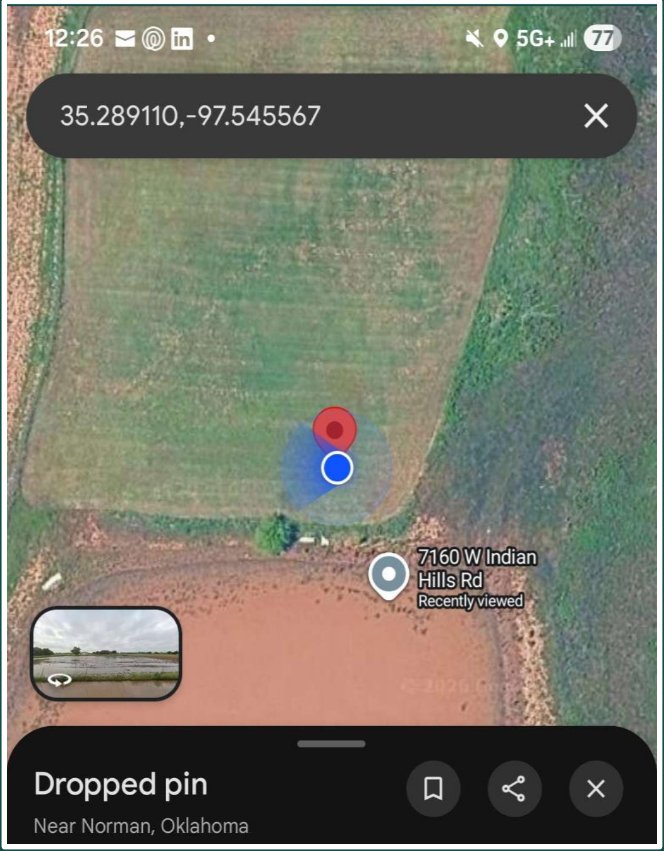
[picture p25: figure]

Mobile App Data | Value
Timestamp (CST) | 4/24/2026 12:26:38 PM
Latitude (Degrees) | 35.28901˚
Longitude (Degrees) | -97.54530˚
Altitude (Meters) | 345.69 m

Location: Farm

Percent Differences:
(calculations in Appendix C)

Latitude: ~2.8 ∗ 10⁻⁴ %

Longitude: ~2.7 ∗ 10⁻⁴ %

Altitude: ~0.378 %

## Testing and Demonstration: GPS Module

AH/
RK

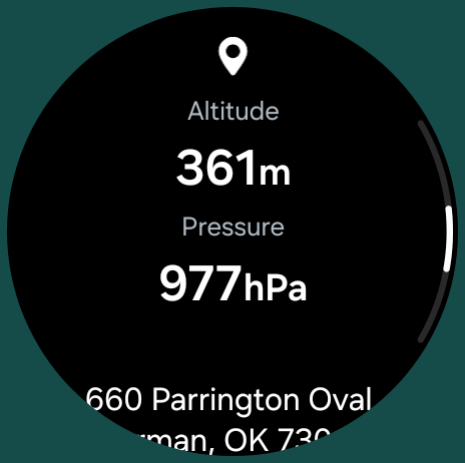
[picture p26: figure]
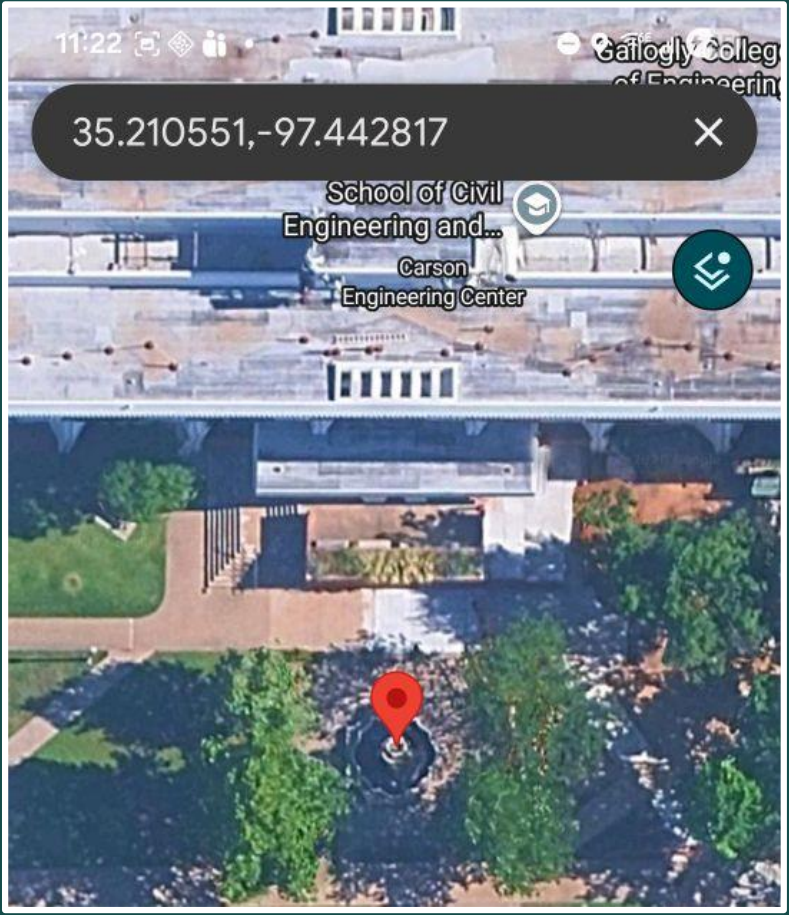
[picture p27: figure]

Mobile App Data | Value
Timestamp (CST) | 4/29/2026 10:17:14 PM
Latitude (Degrees) | 35.21059˚
Longitude (Degrees) | -97.44279˚
Altitude (Meters) | 350.19 m

Location: OU Engineering Quad Fountain Percent Differences:
(calculations in Appendix C)

Latitude: ~1.1 ∗ 10⁻⁴ %

Longitude: ~2.8 ∗ 10⁻⁵ %

Altitude: ~3.040 %

## Testing and Demonstration: GPS Module

AH/
RK

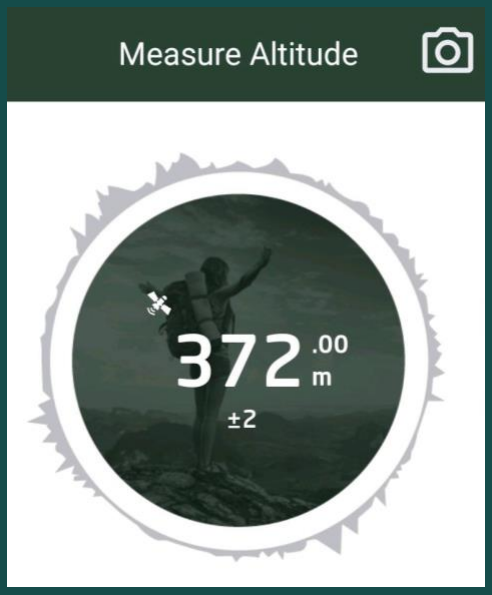
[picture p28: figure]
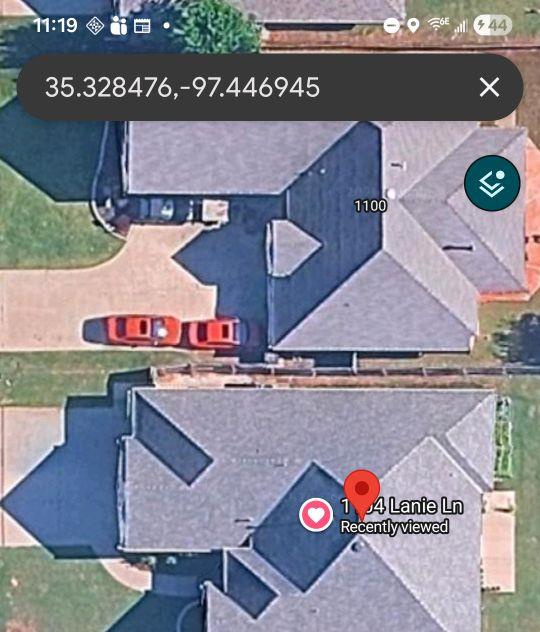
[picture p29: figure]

Mobile App Data | Value
Timestamp (CST) | 4/3/26 20:20:23 PM
Latitude (Degrees) | 35.328664˚
Longitude (Degrees) | -97.446954˚
Altitude (Meters) | 397.80 m

Location: Alex’s Home
Percent Differences:
(calculations in Appendix C)

Latitude: ~5.3 ∗ 10⁻⁴ %

Longitude: ~6.2 ∗ 10⁻⁶ %

Altitude: ~6.703 %

## Testing and Demonstration: Gunshot Detection

AH/
CC

## Brief Overview of Detection Process

## Note: For more details, full software block diagram available in Appendix A

Test #1: Detect audio
spikes (in dB) above a
threshold.

Test #2: Find strong gunshot frequencies (in Hertz) below a certain threshold.

If both tests pass,
then a gunshot has
been detected.
Audio Spike Detection Test | Frequency Detection Test

## Testing and Demonstration: Gunshot Detection


AH/
CC

## Testing and Demonstration: Gunshot Detection


AH/
CC

## Testing and Demonstration: Gunshot Detection

AH/
CC

## Conclusions

## Glock 17: Accuracy ≈ 60%

## AR-15: Accuracy ≈ 83.3%

## (for calculations, see Appendix D)

## - Audio spike detection worked 100% of the time

## - If frequency detection was removed from software, gunshots would be detected 100% of the time

# Final Budget


All

Future Plans • Hardware Future Plans: oooooo • Software Future Plans: ooo


# Questions?

All

# Appendix A

Software Block Diagram


AH

# Appendix B

AH

Battery Calculations; • Battery Life:; • Charge Time:

# Appendix C

GPS Tracking Percent Difference Calculations

Farm:

Latitude:

Percent Difference =

Wlat − Mlat
Wlat + Mlat
2

∗ 100% ≈ 2.8 ∗ 10⁻⁴ %

Longitude:

Percent Difference =

Wlong − Mlong

Wlong + Mlong
2

∗ 100% ≈ 2.7 ∗ 10⁻⁴ %

Altitude:

Percent Difference =

Walt − Malt
Walt + Malt
2

∗ 100% ≈ 0.378 %

AH

Let Wlat represent the latitude obtained from the WAD. Let Wlong represent the longitude obtained from the WAD. Let Walt represent the latitude obtained from the WAD.

Wlat ≈ 35.28901°
Wlong ≈ −97.54530°
Walt ≈ 345.69 m

Let Mlat represent the latitude obtained from a mobile device. Let Mlong represent the latitude obtained from a mobile device. Let Malt represent the latitude obtained from a mobile device.

Mlat ≈ 35.289110°
Mlong ≈ −97.545567°
Malt ≈ 347 m

# Appendix C

GPS Tracking Percent Difference Calculations

OU Engineering Quad Fountain:

Latitude:

Percent Difference =

Wlat − Mlat
Wlat + Mlat
2

∗ 100% ≈ 1.1 ∗ 10⁻⁴ %

Longitude:

Percent Difference =

Wlong − Mlong

Wlong + Mlong
2

∗ 100% ≈ 2.8 ∗ 10⁻⁵ %

Altitude:

Percent Difference =

Walt − Malt
Walt + Malt
2

∗ 100% ≈ 3.040 %

AH

Let Wlat represent the latitude obtained from the WAD. Let Wlong represent the longitude obtained from the WAD. Let Walt represent the latitude obtained from the WAD.

Wlat ≈ 35.21059°
Wlong ≈ −97.44279°
Walt ≈ 350.19 m

Let Mlat represent the latitude obtained from a mobile device. Let Mlong represent the latitude obtained from a mobile device. Let Malt represent the latitude obtained from a mobile device.

Mlat ≈ 35.210551°
Mlong ≈ −97.442817°
Malt ≈ 361 m

# Appendix C

GPS Tracking Percent Difference Calculations

Alex’s Home:

Latitude:

Percent Difference =

Wlat − Mlat
Wlat + Mlat
2

∗ 100% ≈ 5.3 ∗ 10⁻⁴ %

Longitude:

Percent Difference =

Wlong − Mlong

Wlong + Mlong
2

∗ 100% ≈ 6.2 ∗ 10⁻⁶ %

Altitude:

Percent Difference =

Walt − Malt
Walt + Malt
2

∗ 100% ≈ 6.703 %

AH

Let Wlat represent the latitude obtained from the WAD. Let Wlong represent the longitude obtained from the WAD. Let Walt represent the latitude obtained from the WAD.

Wlat ≈ 35.328664°
Wlong ≈ −97.446954°
Walt ≈ 397.80 m

Let Mlat represent the latitude obtained from a mobile device. Let Mlong represent the latitude obtained from a mobile device. Let Malt represent the latitude obtained from a mobile device.

Mlat ≈ 35.328476°
Mlong ≈ −97.446945°
Malt ≈ 372 m

# Appendix D

Gunshot Accuracy Calculations

Glock 17:

Accuracy =

# Gunsℎots Detected

Total # of Gunsℎots

=

3
5

= 60%

AR-15:

Accuracy =

# Gunsℎots Detected

Total # of Gunsℎots

=

5
6

≈ 83. 333%

AH

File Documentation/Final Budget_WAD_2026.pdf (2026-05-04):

# Wearable Alert Device: Final Budget

## University of Oklahoma School of Electrical and Computer Engineering Spring 2026 Semester Senior Capstone Project

## Team Members: Jonas Wollman - Project Manager Ryan Kiesau - Hardware Engineer Cody Chan - Hardware Engineer Alex Ho - Software Engineer

## Written By: Jonas Wollman

Item | Item Description | Quanti ty | Cost $ | Use | Part Number
1 | Arduino Nano ESP32 | 2 | $38.60 | Main Micro controller for project | Mouser - ABX00083
2 | Lithium Ion Battery Pack - 3.7V 4400mAh | 2 | $39.90 | Main Power supply for project | Adafruit - 354
3 | Micro-Lipo Charger for LiPoly Batt with USB Type C Jack | 2 | $11.90 | Rechargable module for Battery Pack | Adafruit - 4410
4 | Gravity: GNSS GPS BeiDou Receiver Module - I2C&UART | 2 | $35.80 | GPS Module for Project | Digikey - 1738-TEL0157-ND
5 | FERMION MEMS MICROPHONE MODULE(Analog) | 2 | $5.80 | Microphone Module for GS Detection | Digikey - SEN0487
6 | 320E11RED | 2 | $4.18 | Button for panic device | Digikey - 101391
7 | MIC2288YD5-TR | 2 | $1.46 | Booster DC DC Converter | Mouser - MIC2288YD5
8 | Breakout Board | 2 | $2.50 | Breakout board for Booster converter | Digikey -1568-00717-ND
9 | SCHOTTKY RECTIFIER | 3 | $0.87 | Schottky diode for GPS Module | Digikey -497-11370-1-ND -Cut Tape (CT)
10 | Testing LED (Red) | 1 | $0.55 | LED used to tell user if device is working | Digikey - SLR-56VC3F
11 | Decupling Capacitor (0.1 Microfarad) | 1 | $0.89 | Used to remove noise from battery pack power | Digikey - C322C104K3G5TA
12 | Current Limiting Resistor(1 KOhm) | 1 | $0.10 | Prevents blow out of LED | Digikey - CFF14JT1K00
13 | Wires(Jumper/Cut) (Spool) | 1 | $15.89 | Came with boards but used to connect device | Half came with the Micro breadboards/ other half from link
14 | Micro Breadboards | 2 | $1.98 | Used to seat device | 6 Pcs Mini Small Breadboard kit White 170 Tie Points
15 | Proto Boards | 2 | $0.56 | Used to more perminently seat device | ELEGOO 32 Pcs Double Sided PCB Board Prototype Kit
16 | Electrical Tape(Roll) | 1 | $0.97 | Used to hold device together before case | Hyper Tough Electrical Tape Single Roll 60 Feet Long Black
| | Total: | $161.95

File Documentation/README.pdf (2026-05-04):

## Senior Capstone Project README: Wearable Alert Device

University of Oklahoma

School of Electrical and Computer Engineering

Semester: Spring 2026

Team Members:

Project Manager - Jonas Wollman

Hardware Engineer - Ryan Kiesau

Hardware Engineer - Cody Chan

Software Engineer - Alex Ho

README written by Alex Ho

GitHub Repository: https://github.com/alnhan/WearableAlertDevice/tree/main

## Overview

This repository contains all project files pertaining to the Wearable Alert Device project. The following information provides guidance for setting up the software development environment as well as a general description of each of the major components of the software.

## Table of Contents

1. Downloading Arduino IDE
2. Initial Environment Setup
- Arduino Nano ESP32 Board Package Installation
- Pin Numbering Setting Configuration
- Required Library Dependencies
- Verifying and Uploading Code to a Microcontroller
3. Software Development
- WearableAlertDevice.ino
- config.h
- WirelessDataTransmission.h/.cpp
- GunshotDetection.h/.cpp

## Downloading Arduino IDE

For this Capstone project, the Arduino IDE was used as the software development environment. The Arduino IDE can be downloaded here. (https://www.arduino.cc/en/software/) Ensure that some version of Arduino IDE 2.0 is downloaded, not the legacy Arduino IDE 1.0.

Back to Table of Contents

## Initial Environment Setup

Once the Arduino IDE has been installed, some initial setup in its environment is needed before code can be correctly uploaded into the Arduino Nano ESP32 microcontroller. There are three important parts to the setup: installing the Arduino Nano ESP32 board package, setting the pin numbering to GPIO numbers, and installing library dependencies.

Back to Table of Contents

## Arduino Nano ESP32 Board Package Installation

The first stage of the environment setup is installing the proper board package so that the environment can correctly compile code and upload programs for Arduino Nano ESP32 microcontrollers. In the Arduino IDE, look on the left for the Boards Manager tab. Click on the Boards Manager tab to open it up.


Figure 1: Screenshot of Boards Manager tab in the Arduino IDE (circled in red).

In the search bar, type "Arduino ESP32 Boards." This package will contain the settings to recognize Arduino Nano ESP32 hardware. Select the Install button if the package is not already installed.


Figure 2: Screenshot of the Arduino ESP32 Boards package not installed yet.

Once the package has been installed, the Arduino IDE will automatically install all the common software libraries associated with ESP32 microcontrollers, such as WiFi, Bluetooth, etc. No additional steps are needed to install these libraries.

Back to Table of Contents

## Pin Numbering Setting Configuration

The software developed for this project has been written specifically to use the Arduino Nano ESP32's GPIO numbers, not the standard Arduino pin numbers that are labeled on the physical device. NOTE: IF THE PIN NUMBERING IS SET TO ARDUINO PIN NUMBERS INSTEAD OF GPIO NUMBERS, THERE WILL BE A GOOD CHANCE THAT INCORRECT PINS ON THE MICROCONTROLLER WILL BE USED BY THE SOFTWARE, WHICH WILL MOST LIKELY PREVENT THE HARDWARE FROM FUNCTIONING PROPERLY.

To change the pin numbering setting in the Arduino IDE, navigate to Tools >>
Pin Numbering | at the ribbon near the top of the IDE. In the Pin Numbering | setting,
there will be two options: By Arduino pin (default) | and By GPIO number

(legacy). Set the Pin Numbering setting to the By GPIO number (legacy) option.

Figure 3: Screenshot of Pin Numbering setting being set to the "By GPIO number (legacy)" option.

The Pin Numbering setting can be found in the Tools tab in the ribbon near the top of the IDE.

Back to Table of Contents

## Required Library Dependencies

There are a few open-source libraries that the software relies on for its functionality. These external libraries are not automatically installed by the Arduino IDE and will have to be installed manually. Below is a list of the open-source libraries:

1. DFRobot_GNSS (https://github.com/DFRobot/DFRobot_GNSS) by DFRobot
2. arduinoFFT (https://github.com/kosme/arduinoFFT) by kosme

The libraries can be downloaded by using the GitHub links above, or they can also be found in the Software/dependencies folder for this project. Once these libraries are downloaded, they need to be installed manually into the Arduino IDE. Navigate to Sketch
>> Include Library >> | Add .ZIP Library... | at the ribbon near the top of
the IDE. After clicking the Add .ZIP Library | option, find the local .zip | files
of the libraries and add them to the Arduino IDE.


Figure 4: Screenshot of the navigation to the "Add .ZIP Library..." option in the Arduino IDE.

Back to Table of Contents

## Verifying and Uploading Code to a Microcontroller

When connecting an Arduino Nano ESP32 microcontroller to the computer for the first time, it is possible that the Arduino IDE does not recognize the hardware as an Arduino Nano ESP32 model specifically. Before verifying or uploading code to the microcontroller, first navigate to Tools >> Board. Ensure that the board type says "Arduino Nano ESP32." If the board type does not say that, set the board type to "Arduino Nano ESP32" by
navigating to Tools >> Board >> Arduino ESP32 Boards and selecting "Arduino Nano ESP32."


Figure 5: Screenshot of the IDE's board type being set to "Arduino Nano ESP32."

To verify that the Arduino IDE properly recognizes the microcontroller as an Arduino Nano ESP32, connect the microcontroller to the computer's USB-A port, and the IDE should display the COM port number and "Arduino Nano ESP32."


Figure 6: Example screenshot of the IDE detecting an Arduino Nano ESP32 on COM Port 10.

Once the IDE properly recognizes the Arduino Nano ESP32, code can now be properly installed on the hardware. There are two important buttons in the IDE for installing
software onto the microcontroller: the Verify | button and Upload | button.
Figure 7: Screenshot of the Verify | button (circled in red) and Upload | button (circled in
green) in the Arduino IDE.

The Verify button, identified by a checkmark symbol, compiles the code and ensures there are no compile errors. This button does not upload the software into the microcontroller. The
Upload | button, identified by an arrow pointing right, performs the same function as the
Verify | button. However, once the code has been successfully compiled, the Upload
button will then upload the software to the connected microcontroller. For best practices, it is best to first press the `Verify` button before pressing `Upload` button when uploading new code to the microcontroller.

Back to Table of Contents

## Software Development

The following section provides a general description of each of the software files. If further details are needed, comments and documentation can be found within the software files themselves.

Back to Table of Contents

## WearableAlertDevice.ino

WearableAlertDevice.ino is the main software file for this project. This file serves as the device's main source for functionality. The Arduino Nano ESP32 will look to this file for how to control the connected hardware. Functions and variables from supporting
files such as config.h, WirelessDataTransmission.h, and GunshotDetection.h can also be used by WearableAlertDevice.ino.

Back to Table of Contents

## config.h

config.h contains all the adjustable settings for the Wearable Alert Device. Instead of going into each of the different software files to change certain settings, which can introduce potential bugs if not carefully done, these settings can be changed directly in config.h, and those changes will automatically propagate throughout the rest of software. As a result, changing a specific setting for the Wearable Alert Device only requires changing a single value in config.h, and developers do not need to parse through all the complex code to change each instance of the setting that appears in the code.

Back to Table of Contents

## WirelessDataTransmission.h/.cpp

WirelessDataTransmission.h handles the software that wirelessly transmits the data from the Wearable Alert Device to a mobile app. For this project, Bluetooth Low-Energy was used as the protocol for transmitting data wirelessly. Thus, WirelessDataTransmission.h contains the software that initializes the microcontroller's Bluetooth Low-Energy module and handles when a mobile device connects or disconnects from the Wearable Alert Device.

Back to Table of Contents

## GunshotDetection.h/.cpp

GunshotDetection.h handles the audio sampling and processing needed to detect a gunshot. This file creates all the necessary buffers that store audio samples collected by the microphone. In addition, the file also performs the mathematical conversions needed to convert the analog voltage from the microphone into a fairly accurate dB Sound Pressure
Level reading. What is important to note about GunshotDetection.h | is that it includes
the previously-mentioned arduinoFFT | library, allowing WearableAlertDevice.ino
to use arduinoFFT's frequency conversion and analysis functions.

Back to Table of Contents

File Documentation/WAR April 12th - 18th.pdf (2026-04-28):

Executive Summary: This week after our team suffered the largest hurdle of last week's

microphone part, we made the most amount of combined progress. The hardware side of our

WAD has finished the first prototype on breadboards and will begin work on the final prototype

on protoboards for the Project Manager to finish in a casing. Once the final prototype is finished

the hardware team plans on finishing all necessary documentation and future planning with a

PCB design. The software team (shoutout solo Alex Ho) got the furthest in solving the gun shot

detection problem then we have so far. Finishing the frequency analysis portion of the software

for the audio signal processing, our team is ready for all testing portions and data gathering for

our final presentation. For the overall documentation side of things, our team knows the

assignments given to them and we are confident that within the remaining two weeks everything

will be accomplished on time if not early!

Hardware:

Cody C.
Progress:
- 4/13 – Hardware building with Ryan (2 Hours 30 Minutes)
- Solder pins to x2 Boost Converter
- Fix soldering pins for Microphone chip
- Finish up wiring for full hardware system on breadboard (~30 Minutes)
- 4/15 – Team meeting (~3 Hours)
- Test full hardware system with hardware system

■ Microphone hardware works outside plugged into laptop

■ Having issues with the battery power. The boost converter is outputting

6.7V with current of 200mA but it does not power the whole hardware

system

- Build full hardware system onto smaller breadboard
- 4/17 – Troubleshoot hardware with Ryan (~2 Hours)
- Conducted multiple testing of the boost converter

■ Added capacitors between Vin and GND to limit the noise

■ Added another capacitor between boost converter and Vin

■ Added diode between output of boost converter to Vin

■ Measured all the testing above with 5V

- Direct connection of 3.7V to Arduino Nano ESP 32 works and powers both GPS

and microphone with Bluetooth

■ Conducted field testing to make sure it works outside

■ Received signal walking around outside with 3.7V battery

- Direct connection with DC power supply stepping down

■ Found out that the whole system will run all the way down to 2.8V before

everything turns off.

Total Hours Worked: ~ 8 Hours

Future Work/Plan

- Figure out how long the run time?
- Update GitHub
- Start Protoboard

- Research how to create a PCB for the prototype to have 3D model to show
- Start/Create Hardware Documentation

Hardware:

Ryan K.
Progress:
- 4/13 - Constructing Hardware (~3hrs)
- Solder components that needed it
- Wired and troubleshoot complete device
- 4/15 - Team Meeting (~2hrs)
- Tested all components of the device
- Could not get the device to work independently
- 4/17 - Hardware Troubleshooting (~2hrs)
- Troubleshoot boost converter to get the device to work independently
- Tested device without boost converter, which causes everything to work properly
- Tested different voltage values to the Arduino to see when a direct connection

from the battery would become obsolete

Total Hours Worked: ~7 Hours

Future Work/Plan:

- Construct Protoboard
- Begin writing required hardware documentation

Software:

Alex H.

Progress:

- 4/14 (2 h 7 min)
- Readjusted internal settings inside of the software to configure the GPS updates to

occur approximately every 1 second

- Developed new software that accurately lowers the audio dB levels to more

realistic readings.

- Collected readings from the analog microphone to determine the average

noise floor of the microphone. Compared readings from the Wearable

Alert Device with a sound meter mobile app. The average noise floor

appeared to be about 15 dB.

- New software subtracts about 15 dB from the raw dB values to filter out

the noise floor. Made this subtraction value easily customizable. If future

developers want to use a different value instead of 15 dB, they just need to

change a single number in the config.h file.

- Combined peak detection software with Bluetooth software so that whenever a dB

reading exceeds the customizable threshold, it will automatically transmit the data

wirelessly without the need to press a button.

- 4/15 (1 h 58 min)
- Tested new audio software with the team. Other team members seem to be

satisfied with the current state of the audio software.

- Performed numerous tests with the peak detection, adjusting the gunshot dB

threshold level to see what would be a reasonable threshold to set the device to for

the final demonstration.

- Troubleshooted boost converter issues with the hardware portion of the device.
- 4/19 (6 h 14 min)
- Developed frequency analysis portion of the software for the audio signal

processing.

- Applies a Hamming window function to the voltages output by the

microphone.

- Performs the Fast Fourier Transform on the voltages to obtain a list of the

strongest energy magnitudes in the audio signal and their associated

frequencies.

- Based on research, the muzzle blast from gunshots have the most energy

below 500 Hz, so the software checks if the highest magnitude of energy

is somewhere near this 500 Hz value by a certain margin. This margin is

also easily customizable by future software developers, as only a single

number needs to be changed to adjust it.

- Started writing the user manual for the Wearable Alert Device.
- Started writing the README file for the Wearable Alert Device on the GitHub

project repository, which will eventually be converted into a standard doc/pdf file

to become the project’s software documentation.

Total Hours Worked: 10 h 19 min

Future Work/Plan:

- Continue writing user manual
- Continue writing README/software documentation

- Develop some form of methodology of proper, valid data collection so that we can

present some solid data at the final demonstration.

Project Manager:

Jonas W.
Progress:
- 4/15 – Team meeting (~2 Hours)
- Test full software system with hardware
- Found issue of the board not working independently with the battery pack.
- Scheduled plans between hardware group to resolve issue and find game plan
- 4/16 PM Work (1 Hour)
- Reschedule the Final Demo Presentation
- Work on the BOM
- 4/17 Potential Casing Work (1 Hour)
- Research on how and where to build case for the device one Hardware is finished

on protoboard

- Research on which modeling software to use and if it would be worth the time

this semester to have ready for next semester's group

- Re did OU Fabrication Lab certifications so I could have access to 3D printing at

their facilities

- 4/18 PM Purchases/ PM Work (1 Hour)
- Purchased binders for final demo booklet
- Purchased paper for the 11x7 schematics to be printed on
- Worked on outline of Final DEMO booklet

Total Hours Worked: ~5 Hours

Future Work/Plan:

- Continue work on the User Manual help
- Continue work on formatting and helping with hardware design document
- Continue work on BOM and Final Demo Booklet/ Slides
- Continue work on Casing for final prototype
- Reach out to when we can go test the gun shot detection for possibly week on 27th

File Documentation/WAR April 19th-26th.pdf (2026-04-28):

Executive Summary: This week the team made significant strides in finishing the WAD final

prototype, our device is working and getting all the information and data needed. This means that

the last thing to finish is the overall case and documentation of the WAD. We successfully

completed field testing for gunshot and GPS accuracy by going out to private property and

shooting guns and testing the overall location accuracy while out of city limits. Overall on the

hardware side, the assembly, trouble shooting, and final optimization/build of the WAD

prototype is completed. For the software side, the documentation is getting completed in the

README file and the overall data processing of the WAD. Next week the team plans on

finalizing the WAD with all documentation and presentation slides. This means the completion

of the Estimated battery runtime/ pcb design. Finishing the Hardware design document and

software manual. Then finally completing, polishing, and practicing the Final Demo slides for

the end of semester final presentation on Monday May 4th.

Hardware:

Cody C.
Progress:
- 4/22 – Team meeting (~2 Hours 30 Minutes)
- Uploaded full code to the Arduino Nano ESP32
- Talked about next steps for testing the Gunshot detection

■ Scheduled field testing for Friday, April 24th at 12pm to test the gunshot

detection, as well as how well the GPS works.

- Measured the current flow between battery and Arduino Nano ESP32

■ 167 mA flowing through.

- Leave the working product on a breadboard but create a working project onto a

protoboard.

■ Soldered on components to the protoboard

■ Ryan soldered the Arduino ESP32 to the protoboard and

microphone. I soldered the GPS wires to the ESP32 and ran testing

by directly connecting the ESP32 to a laptop. Bluetooth works and

it receives the GPS and Gunshot decibel readings on the phone.

- Updated Schematics for the CCEW Wearable Device (~20 Minutes)
- Create wiring diagram for the Wearable Device (~20 Minutes)
- Updated GitHub Repo (~50 Minutes)
- Organize Hardware GitHub Repo
- Get electrical tape to combine the components together
- 4/23 – Finish up soldering in the capstone lab (~ 1 Hour)
- Solder on the LIPO Charger and connect the pins together and run all testing
- After some testing, everything works (Bluetooth, GPS, and Microphone),

however, the button does not work.

- 4/24 –
- Troubleshoot button problem and add on LED (~1 Hour)

■ Meet with Ryan to figure out button problem

■ Desolder the wire connected to the button and resolder them back

on

- Field testing for GPS and Gunshot detection with the team (~1 Hours)

■ Gunshot detection:

■ Tested with 5 mm pistol and AR-15 rifle

■ Take software readings of the data

■ Run multiple test incrementing further back to test how far the

device can go before it can not detect a gunshot

■ Wearable Alert Device was able to detect gunshots majority of the

time

- Fix protoboard wiring (~1 Hour 30 Minutes)

■ Fix soldering and wiring of the protoboard and make it compact

■ Move breadboard version into smaller breadboards

- 4/25 –
- Quick team meeting (~15 Minutes)

■ Talk about presentation

■ Delegate who needs to work on what on the presentation

■ Ryan: GPS, boost converter change

■ Cody: Microphone, microphone change

- Reorganize smaller breadboard (~30 Minutes)

■ Cut smaller wires for small breadboard and create a compact version

■ Take pictures of the protoboard version and smaller breadboard version

Total Hours Worked: ~ 9 Hours 15 Minutes

Future Work/Plan

- Calculate Estimated runtime
- Start Hardware Documentation

- Start Final Presentation

Hardware:

Ryan K.
Progress:
- 4/22 - Team Meeting (~2 hrs)
- Went over future plans and important dates
- Constructed the majority of the protoboard

■ Connected everything but the LIPO charger, GPS, and LED

■ Button could not be picked up by the arduino

- 4/24 - Protoboard Cleanup and Field Testing (~2hrs)
- Complete protoboard

■ Added remaining components and fixed button issue

- Tested and recorded real data for the GPS and microphone
- 4/25 - Team Meeting (~15min)
- Quickly went over the upcoming due dates and had all out Final Demo slides

assigned and outlined

Total Hours Worked: 4hr 15min

Future Work/Plan:

- Start and complete all hardware specific documentation
- Start, finish, and practice Final Demo slides with team

Software:

Alex H.

Progress:

- 4/20 (3 h 21 min)
- Wrote most of the README file for the software development documentation on

the GitHub repository, providing details of how to install the Arduino IDE, library

dependencies, and how to set up the software development environment.

- Created a cover page for the user manual.
- Created two folders in the GitHub repository, one for the documentation and one

for the presentations.

- 4/22 (2 h 7 min)
- Finished writing the README file for the software development documentation.
- Assisted hardware team members with soldering the final prototype of the

Wearable Alert Device.

- 4/24 (50 min)
- Drove to a volunteer’s private property to fire some guns to test the performance

of the Wearable Alert Device.

- A 5 mm pistol and AR-15 rifle were the two firearms used for this test.
- To collect data, the team screen-recorded a phone that had the nRF

Connect mobile app. Simultaneously, the computer screen containing the

Serial messages from the Wearable Alert Device was also recorded, and

the volunteer firing the guns was also recorded.

- Made slight adjustments to the Wearable Alert Device’s internal settings

so that it picks up a gunshot better.

- Wearable Alert Device was able to detect a gunshot most of the time.

- 4/26 (3 h)
- Converted README.md file from GitHub repository into a Word doc so that it

can be easily accessible for anyone without the need for a GitHub account.

- Processed data from testing into a nice and presentable format
- Data will be presented at the final demonstration in the form of a video,

where it will show the nRF Connect mobile app, live footage of firing the

guns, and a readable table of the data from the mobile app. When the live

footage shows a gun being fired, the app and table will update in the

video.

- Began writing nRF Connect app setup section for the user manual.

Total Hours Worked: 9 h 18 min

Future Work/Plan:

- Finish writing the user manual
- Complete final demonstration presentation slides
- Practice final demonstration presentation slides with the team
- Prepare and gather all the project files to store in the USB flash drives.

Project Manager:

Jonas W.
Progress:
- 4/22 – Team meeting (~1 Hours 30 Minutes)
- Schedule field testing day, work on documentation
- Worked on the beginnings of the Hardware design Document
- Worked on the beginnings of the Software User manual

- Work with volunteer to double check date and time for testing of gunshot

detection and get everything confirmed

- 4/23 – Presentation (~1 Hours)
- Create slides, theme and transition for presentation for Final Demo
- Worked on some of the layout and outline of the overall presentation but needed

to talk with team about promised deliverables

- 4/24 – Field testing (~1 Hours)
- Worked with volunteer at their property to fire guns to get data for thw WAD
- Fires two guns 1 being a glock 17 pistol and the other an AR-15, Gunshot

detection worked majority of the time

- Had to make several adjustments during the testing
- Took video and screen recordings of data for final presentation
- 4/25 - Mini Team meeting (~30 Minutes)
- Personally worked on mapping out the outline of the final presentation slides
- Shared with team what I thought would be the best course of action and made

sure everyone was on the same page to end strong

- 4/26 - Self preparation and documentation management (~2 Hours)
- Worked on more ideas and sketches to begin working on the case of the WAD

before taking measurements on Monday 4/27.

- More refreshing on Autodesk inventor so that once measurements are taken I can

create the STL files and have them ready to print this week.

- Began moving documents over to flashdrives of archive so that when everything

begins getting done and I move over to the git hub it will be easier to make the final movements to the final archive

Total Hours Worked: 6 Hours

Future Work/Plan:

- Take measurements of the Protoboard WAD for case building
- Create and print case for WAD
- Finish final presentation slides
- Practice final presentation
- Finish files and documentations
- Finish file archive

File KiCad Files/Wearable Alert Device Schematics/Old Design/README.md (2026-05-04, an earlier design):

# Old Designs of the Wearable Alert Device

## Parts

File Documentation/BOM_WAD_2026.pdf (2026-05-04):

# Wearable Alert Device: BOM

## University of Oklahoma School of Electrical and Computer Engineering Spring 2026 Semester Senior Capstone Project

## Team Members: Jonas Wollman - Project Manager Ryan Kiesau - Hardware Engineer Cody Chan - Hardware Engineer Alex Ho - Software Engineer

## Written By: Jonas Wollman

Item | Item Description | Quantity | Cost $ | Use | Part Number
1 | Arduino Nano ESP32 | 1 | $19.30 | Main Micro controller for project | Mouser - ABX00083
2 | Lithium Ion Battery Pack - 3.7V 4400mAh | 1 | $19.95 | Main Power supply for project | Adafruit - 354
3 | Micro-Lipo Charger for LiPoly Batt with USB Type C Jack | 1 | $5.95 | Rechargable module for Battery Pack | Adafruit - 4410
4 | Gravity: GNSS GPS BeiDou Receiver Module - I2C&UART | 1 | $17.90 | GPS Module for Project | Digikey - 1738-TEL0157-ND
5 | FERMION MEMS MICROPHONE MODULE(Analog) | 1 | $2.90 | Microphone Module for GS Detection | Digikey - SEN0487
6 | 320E11RED | 1 | $2.09 | Button for panic device | Digikey - 101391
7 | Testing LED (Red) | 1 | $0.55 | LED used to tell user if device is working | Digikey - SLR-56VC3F
8 | Decupling Capacitor (0.1 Microfarad) | 1 | $0.89 | Used to remove noise from battery pack power | Digikey - C322C104K3G5TA
9 | Current Limiting Resistor(1 KOhm) | 1 | $0.10 | Prevents blow out of LED | Digikey - CFF14JT1K00
10 | Wires(Jumper/Cut) (Spool) | 1 | $15.89 | Came with boards but used to connect device | Half came with the Micro breadboards/ other half from link
11 | Proto Boards | 1 | $0.28 | Used to more perminently seat device | ELEGOO 32 Pcs Double Sided PCB Board Prototype Kit
12 | Electrical Tape(Roll) | 1 | $0.97 | Used to hold device together before case | Hyper Tough Electrical Tape Single Roll 60 Feet Long Black
| | Total: | $86.77

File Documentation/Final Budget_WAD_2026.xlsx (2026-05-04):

Item | Item Description | Quantity | Cost $ | Use | Part Number | Link
1 | Arduino Nano ESP32 | 2 | $38.60 | Main Micro controller for project | Mouser - ABX00083 | ABX00083 Arduino | Mouser (https://www.mouser.com/ProductDetail/Arduino/ABX00083?qs=ulEaXIWI0c8OkA6u7pnNRA%3D%3D)
2 | Lithium Ion Battery Pack - 3.7V 4400mAh | 2 | $39.90 | Main Power supply for project | Adafruit - 354 | https://www.adafruit.com/product/354
3 | Micro-Lipo Charger for LiPoly Batt with USB Type C Jack | 2 | $11.90 | Rechargable module for Battery Pack | Adafruit - 4410 | https://www.adafruit.com/product/4410
4 | Gravity: GNSS GPS BeiDou Receiver Module - I2C&UART | 2 | $35.80 | GPS Module for Project | Digikey - 1738-TEL0157-ND | https://www.digikey.com/en/products/detail/dfrobot/TEL0157/18069252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
5 | FERMION MEMS MICROPHONE MODULE(Analog) | 2 | $5.80 | Microphone Module for GS Detection | Digikey - SEN0487 | https://www.digikey.com/en/products/detail/dfrobot/SEN0487/14824939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
6 | 320E11RED | 2 | $4.18 | Button for panic device | Digikey - 101391 | https://www.digikey.com/en/products/detail/e-switch/320E11RED/101391
7 | MIC2288YD5-TR | 2 | $1.46 | Booster DC DC Converter | Mouser - MIC2288YD5 | https://www.mouser.com/ProductDetail/Microchip-Technology/MIC2288YD5-TR?qs=Y3Q3JoKAO1S0eR8M4KE3QA%3D%3D
8 | Breakout Board | 2 | $2.50 | Breakout board for Booster converter | Digikey - 1568-00717-ND | https://www.digikey.com/en/products/detail/sparkfun-electronics/00717/5318740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
9 | SCHOTTKY RECTIFIER | 3 | $0.87 | Schottky diode for GPS Module | Digikey -497-11370-1-ND - Cut Tape (CT) | https://www.digikey.com/en/products/detail/stmicroelectronics/1N5822/2674533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
10 | Testing LED (Red) | 1 | $0.55 | LED used to tell user if device is working | Digikey - SLR-56VC3F | https://www.digikey.com/en/products/detail/rohm-semiconductor/SLR-56VC3F/636991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
11 | Decupling Capacitor (0.1 Microfarad) | 1 | $0.89 | Used to remove noise from battery pack power | Digikey - C322C104K3G5TA | https://www.digikey.com/en/products/detail/kemet/C322C104K3G5TA/6656629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
12 | Current Limiting Resistor(1 KOhm) | 1 | $0.10 | Prevents blow out of LED | Digikey - CFF14JT1K00 | https://www.digikey.com/en/products/detail/stackpole-electronics-inc/CFF14JT1K00/6269804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
13 | Wires(Jumper/Cut) (Spool) | 1 | $15.89 | Came with boards but used to connect device | Half came with the Micro breadboards/ other half from link | https://www.amazon.com/dp/B07TX6BX47?amp=&amp=
14 | Micro Breadboards | 2 | $1.98 | Used to seat device | 6 Pcs Mini Small Breadboard kit White 170 Tie Points | https://www.amazon.com/dp/B09YXQJMTG?ref=ppx_yo2ov_dt_b_fed_asin_title
15 | Proto Boards | 2 | $0.56 | Used to more perminently seat device | ELEGOO 32 Pcs Double Sided PCB Board Prototype Kit | https://www.amazon.com/ELEGOO-Prototype-Soldering-Compatible-Arduino/dp/B072Z7Y19F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
16 | Electrical Tape(Roll) | 1 | $0.97 | Used to hold device together before case | Hyper Tough Electrical Tape Single Roll 60 Feet Long Black | https://www.walmart.com/ip/Hyper-Tough-Electrical-Tape/13709008395?wmlspartner=wlpa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
 |  | Total: | $161.95
Item | Item Description | Quantity | Cost $ | Use | Part Number | Link
1 | Arduino Nano ESP32 | 1 | $19.30 | Main Micro controller for project | Mouser - ABX00083 | ABX00083 Arduino | Mouser (https://www.mouser.com/ProductDetail/Arduino/ABX00083?qs=ulEaXIWI0c8OkA6u7pnNRA%3D%3D)
2 | Lithium Ion Battery Pack - 3.7V 4400mAh | 1 | $19.95 | Main Power supply for project | Adafruit - 354 | https://www.adafruit.com/product/354
3 | Micro-Lipo Charger for LiPoly Batt with USB Type C Jack | 1 | $5.95 | Rechargable module for Battery Pack | Adafruit - 4410 | https://www.adafruit.com/product/4410
4 | Gravity: GNSS GPS BeiDou Receiver Module - I2C&UART | 1 | $17.90 | GPS Module for Project | Digikey - 1738-TEL0157-ND | https://www.digikey.com/en/products/detail/dfrobot/TEL0157/18069252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
5 | FERMION MEMS MICROPHONE MODULE(Analog) | 1 | $2.90 | Microphone Module for GS Detection | Digikey - SEN0487 | https://www.digikey.com/en/products/detail/dfrobot/SEN0487/14824939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
6 | 320E11RED | 1 | $2.09 | Button for panic device | Digikey - 101391 | https://www.digikey.com/en/products/detail/e-switch/320E11RED/101391
7 | Testing LED (Red) | 1 | $0.55 | LED used to tell user if device is working | Digikey - SLR-56VC3F | https://www.digikey.com/en/products/detail/rohm-semiconductor/SLR-56VC3F/636991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
8 | Decupling Capacitor (0.1 Microfarad) | 1 | $0.89 | Used to remove noise from battery pack power | Digikey - C322C104K3G5TA | https://www.digikey.com/en/products/detail/kemet/C322C104K3G5TA/6656629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
9 | Current Limiting Resistor(1 KOhm) | 1 | $0.10 | Prevents blow out of LED | Digikey - CFF14JT1K00 | https://www.digikey.com/en/products/detail/stackpole-electronics-inc/CFF14JT1K00/6269804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
10 | Wires(Jumper/Cut) (Spool) | 1 | $15.89 | Came with boards but used to connect device | Half came with the Micro breadboards/ other half from link | https://www.amazon.com/dp/B07TX6BX47?amp=&amp=
11 | Proto Boards | 1 | $0.28 | Used to more perminently seat device | ELEGOO 32 Pcs Double Sided PCB Board Prototype Kit | https://www.amazon.com/ELEGOO-Prototype-Soldering-Compatible-Arduino/dp/B072Z7Y19F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
12 | Electrical Tape(Roll) | 1 | $0.97 | Used to hold device together before case | Hyper Tough Electrical Tape Single Roll 60 Feet Long Black | https://www.walmart.com/ip/Hyper-Tough-Electrical-Tape/13709008395?wmlspartner=wlpa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
 |  | Total: | $86.77

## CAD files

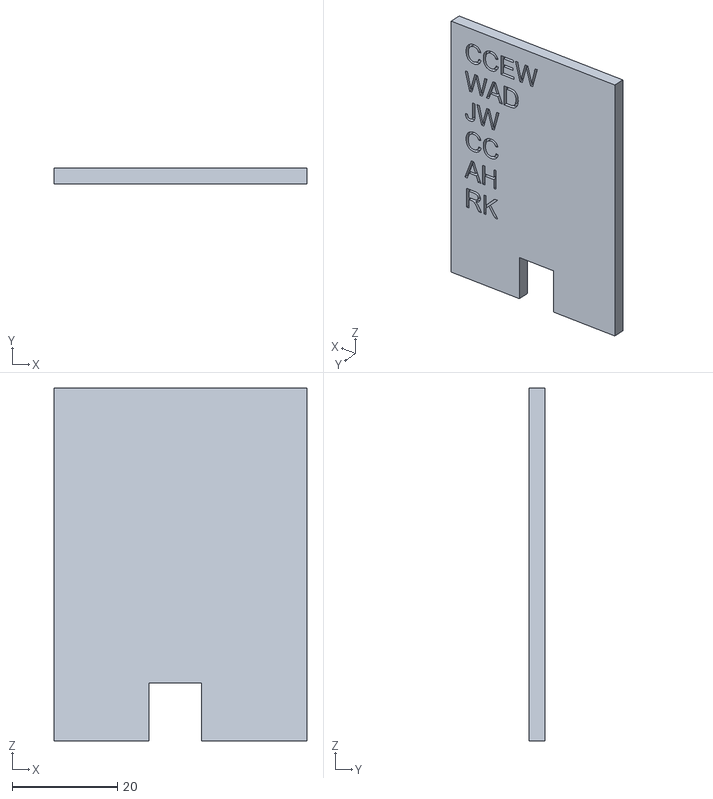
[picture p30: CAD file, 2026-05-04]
Documentation/Case Files/Box Cap.stl
48.0 x 3.00 x 67.0

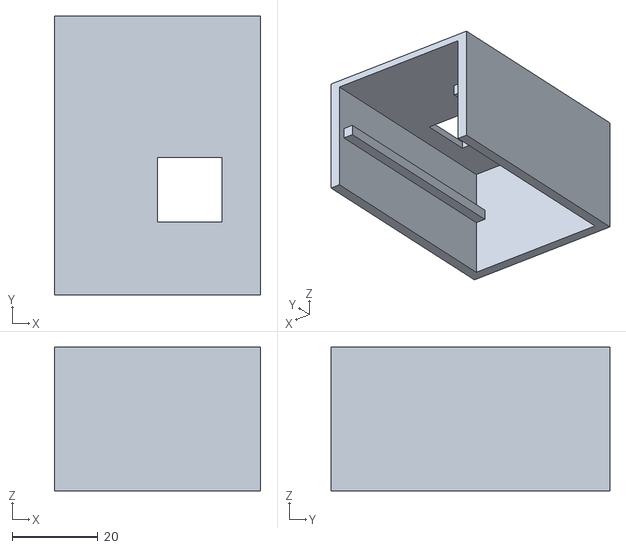
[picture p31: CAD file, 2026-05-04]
Documentation/Case Files/Box Right Top Half.stl
48.0 x 65.0 x 33.5

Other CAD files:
Documentation/Case Files/Box Right bottom Half.stl
Documentation/Case Files/Box Right Top Half.obj
Documentation/Case Files/Box Right bottom Half.obj

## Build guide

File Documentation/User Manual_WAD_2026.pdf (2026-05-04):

## Wearable Alert Device: User Manual

University of Oklahoma
School of Electrical and Computer Engineering Spring 2026 Semester
Senior Capstone Project

Team Members:
Jonas Wollman - Project Manager Ryan Kiesau - Hardware Engineer Cody Chan - Hardware Engineer Alex Ho - Software Engineer

Written By:
Jonas Wollman
Alex Ho

Table of Contents

Overview | 1
Features | 1
Wireless Data Transmission | 2
GPS Tracking | 3
Gunshot Detection | 3
User Operation | 3
Powering the Device | 4
Using the nRF Connect for Mobile App | 6
Button Operation | 16

Overview

This section describes the details of the CCEW Wearable Alert Device (WAD), provides

a block diagram showing the major functional units, and how the WAD’s software

implementation works with the specific chips on the device.

The WAD’s mission is to create a discrete device that could be worn in case of emergency

assistance. The overall goal of the WAD is to alert authorities on location, elevation, and an

immediate threat such as a gunshot.

The intended audience that we are building the device for is not that of first responders.

Instead we are thinking about secondary responders who may not have field training but may

still be in dangerous scenarios while working. This device is made for them to have a way of

contacting authorities while not giving too much information to the potential assailant.

Features

The following section lists all of the key features of the Wearable Alert Device. For this

iteration of the Wearable Alert Device, there are three major components of its functionality.

First, the WAD provides wireless data transmission via Bluetooth Low-Energy (BLE) to any

Bluetooth Serial messaging mobile app. Second, the WAD contains GPS tracking functionality

that records the current coordinates, time, and altitude. Finally, the WAD has the ability to detect

gunshots and automatically alert emergency responders when detected.

Wireless Data Transmission

To share with authorities important information of the current situation a secondary

responder is in, the WAD wirelessly transmits data using Bluetooth Low-Energy (BLE) protocol.

There are two main scenarios that the WAD wirelessly sends data for, where the first scenario

requires manual transmission and the second scenario utilizes automatic data transmission. For

the first scenario, whenever a secondary responder presses the device’s button, the device will

transmit data. For the second scenario, if a gunshot is detected by the microphone, the WAD will

automatically transmit data. The following table is a list of the data that the WAD sends every

transmission.

Table 1: List of data that the Wearable Alert Device transmits.

Type of Data | Unit of Data
Timestamp | “year-month-day hour-minute-second” (CST)
Latitude | Degrees
Longitude | Degrees
Altitude | Meters
Max Audio Reading | dB Sound Pressure Level
Gunshot Detected? | True/False
Call Emergency Responders? | True/False

Whenever these two scenarios occur, the WAD will package all this data together in a little

packet and send it off in JavaScript Object Notation (JSON) format. JSON is a standard file

format and should be easily readable by any mobile app developed in the future to work with the

WAD.

GPS Tracking

The Wearable Alert Device contains GPS tracking technology that constantly records the

current time, its current location, and its current altitude. This information is incredibly useful for

emergency responders who need to address an urgent situation, allowing them to respond faster.

Gunshot Detection

Containing a regular analog microphone, the WAD can detect gunshots nearby with a fair

amount of accuracy. Utilizing some audio signal processing, the WAD has the capability to

distinguish gunshots from other loud noises such as loud claps or yelling. As mentioned before,

successfully detecting a gunshot will make the WAD automatically transmit data to a mobile

device.

User Operation

The following section describes how to properly operate the Wearable Alert Device. Do

note that there are certain features, such as the gunshot detection and GPS tracking, that run in

the background without the need of manual user operation. Thus, these features will not be

discussed. Primarily, the main features that require manual user operation include powering the

device, setting up the mobile app, and pressing the button.

Powering the Device

In this section it will be explained how the device is powered on and how to maintain

power to the device. Our WAD utilizes two main power supplies to all our chips and modules.

The first way is only accessible in our prototype and not in the final device. Simply connect a

USB-C power port located on the device to a standard power outlet or source with a USB

adapter. This method will then power the rest of the modules, making the device work while

plugged into a laptop, for example.

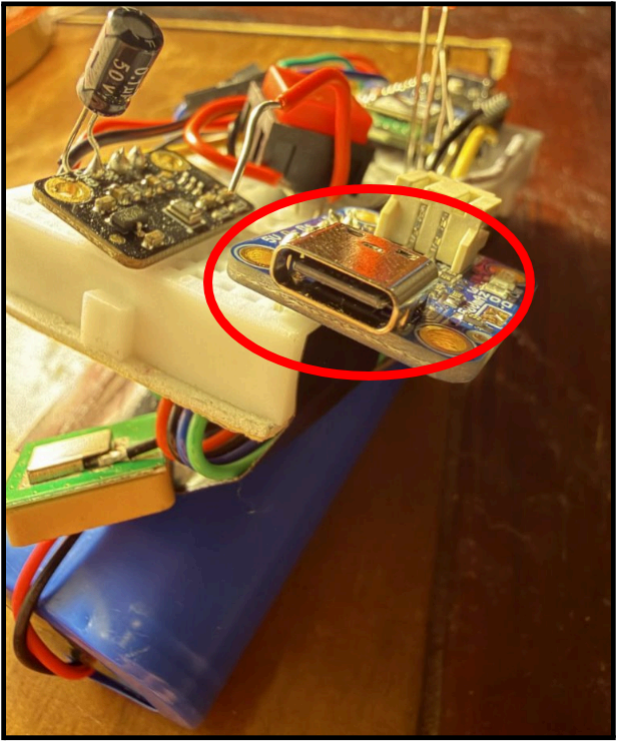
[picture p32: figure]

Figure 1: The USB-C Charging Port

The second way of powering our device is by having the battery on the protoboard charged. The

device does not have an ‘on - off’ switch meaning that when the battery is connected, the device will always be running. This means that as long as the battery has charge you will be able to

power and use the entire device and its features.

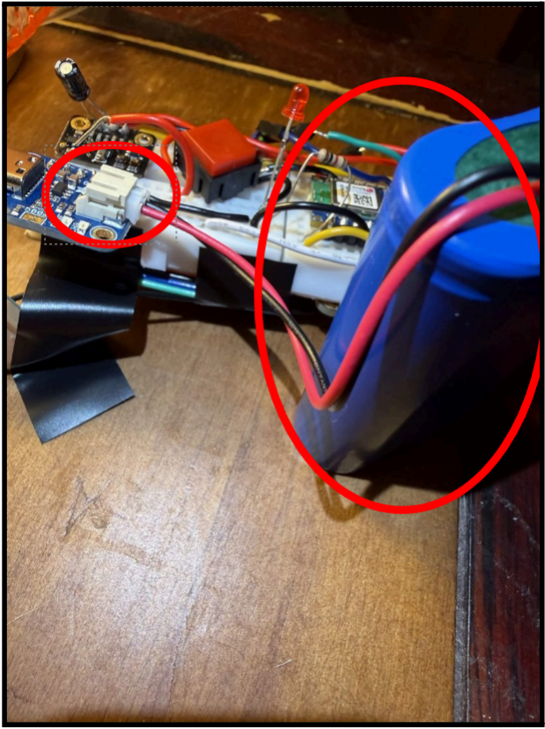
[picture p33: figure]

Figure 2: The Battery and the Power Port to Charger

Some key issues to keep in mind when dealing with the powering of the device.

Reference the Hardware design document for detailed information on how the battery is charged

and where the correct connections are for the prototypes. Since the battery is always plugged in

and the device is technically always on, the battery drain is significant and if there are issues

even after charging the battery, there may be a dead battery inside the device itself.

Using the nRF Connect for Mobile App

The nRF Connect for Mobile app is a Bluetooth serial messaging app that was used

during this project to simulate a mobile app from the CCEW group. Therefore, this user manual

is tailored towards usage of this specific Bluetooth serial messaging app. If a different Bluetooth

serial messaging app is used, different steps on the mobile app may need to be taken to receive

data from a WAD. nRF Connect is available for Android and IOS, and no account is needed,

meaning that anyone can download and connect to the WAD. The following steps will take you

through setting up this app to receive data from a WAD.

1. Enable Bluetooth on your mobile device.
2. If you do not have it already, download the nRF Connect app onto your mobile device

and then open the app.

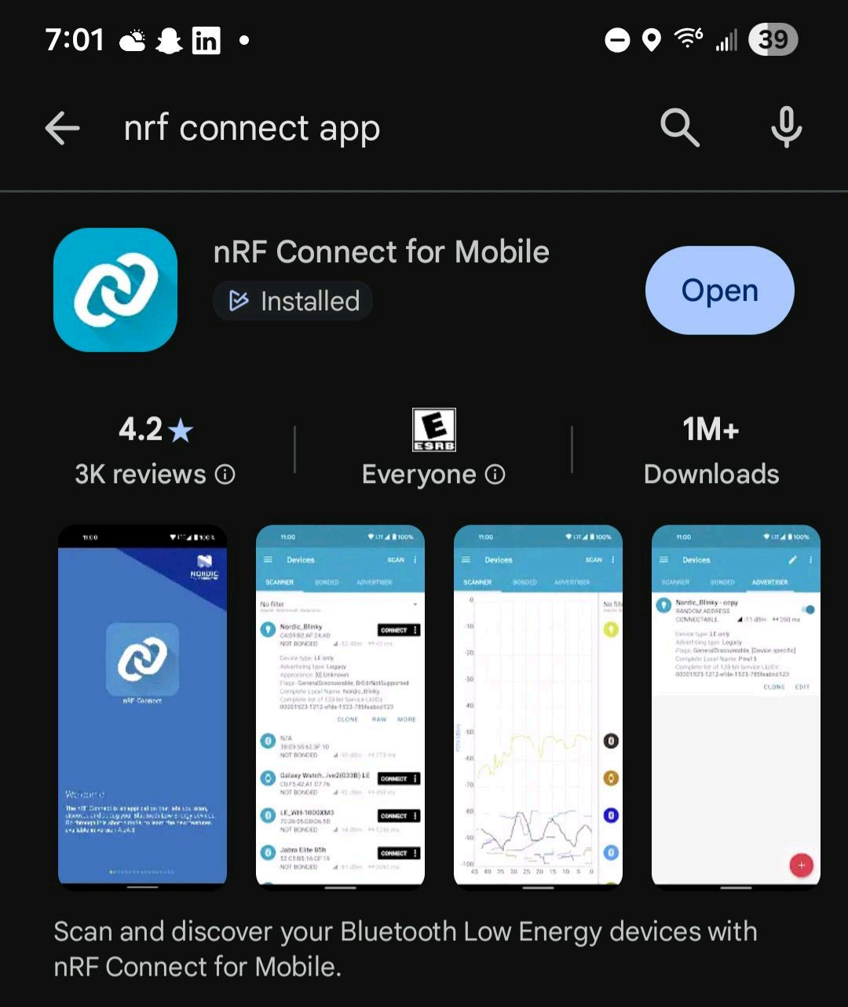
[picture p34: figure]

Figure 3: Screenshot of nRF Connect for Mobile app in the Google Play Store on an Android phone.

3. When you first open the app, you will be on the “Devices” tab, where you will be able to

see all Bluetooth devices nearby. At the top right, there will be a button that says “Scan”.

Select that button to start scanning for Wearable Alert Devices.

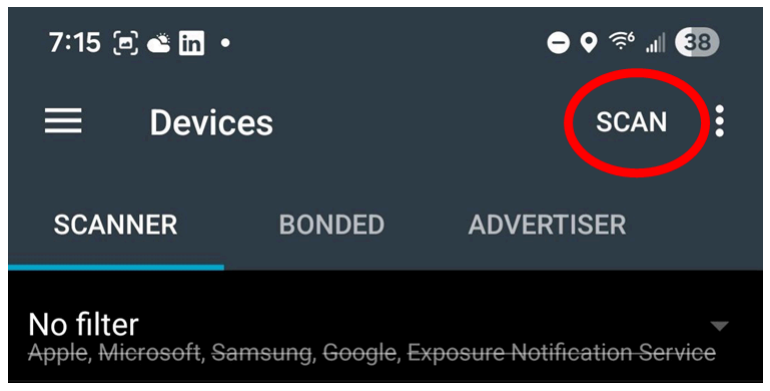
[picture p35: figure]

Figure 4: Screenshot of Devices tab in nRF Connect, with the Scan button circled in red.

4. If a powered Wearable Alert Device is nearby, it will appear on the Devices tab as shown

below in Figure 5. Select the “Connect” button to connect to the WAD.

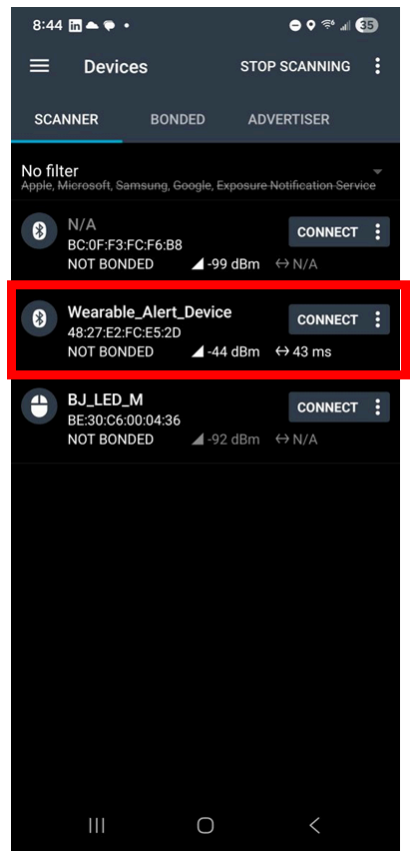
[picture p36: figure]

Figure 5: Screenshot of the Wearable Alert Device appearing in the Devices tab.

5. Once connected, you will see this tab for the Wearable Alert Device, as seen in Figure 6.

There are a few settings to configure so that you can actually see the data the WAD

transmits.

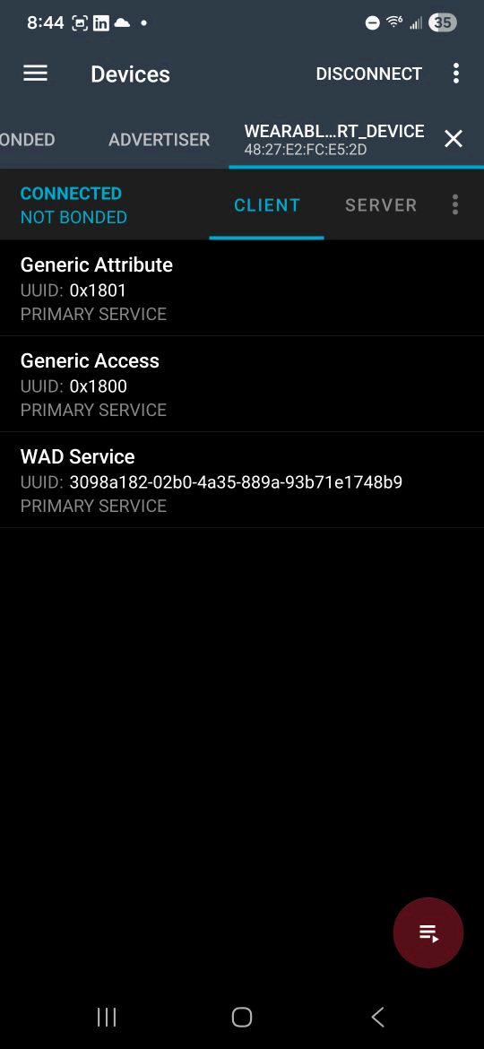
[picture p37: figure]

Figure 6: Screenshot of the “Wearable_Alert_Device” tab on nRF Connect app after connecting to a WAD.

6. Select the section labeled “WAD Service” to expand its information (boxed in red in

Figure 7). To the right, you will see an icon with three arrows (circled in green in Figure

7). Select this icon to enable live notifications for new WAD data. This icon will be

crossed out when it has been selected, and there will be a line of text saying

“Notifications enabled” (see Figure 8).

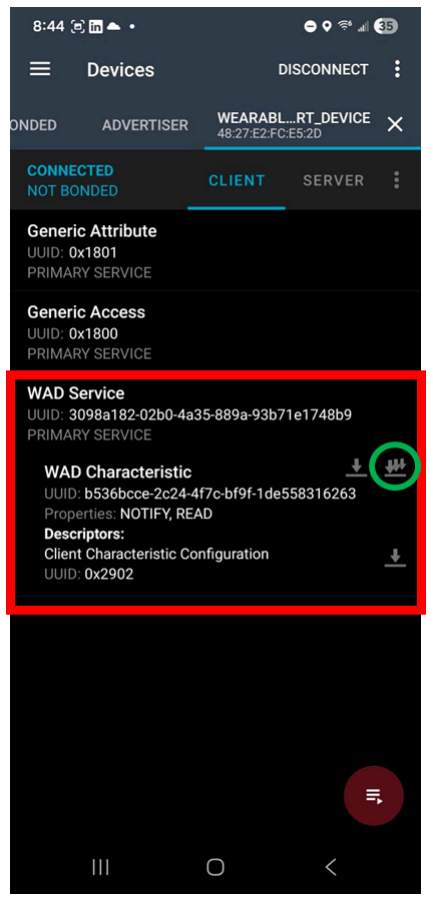
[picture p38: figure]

Figure 7: Screenshot of WAD Service section expanded (boxed in red) and the “Enable Notifications” icon (circled in green).

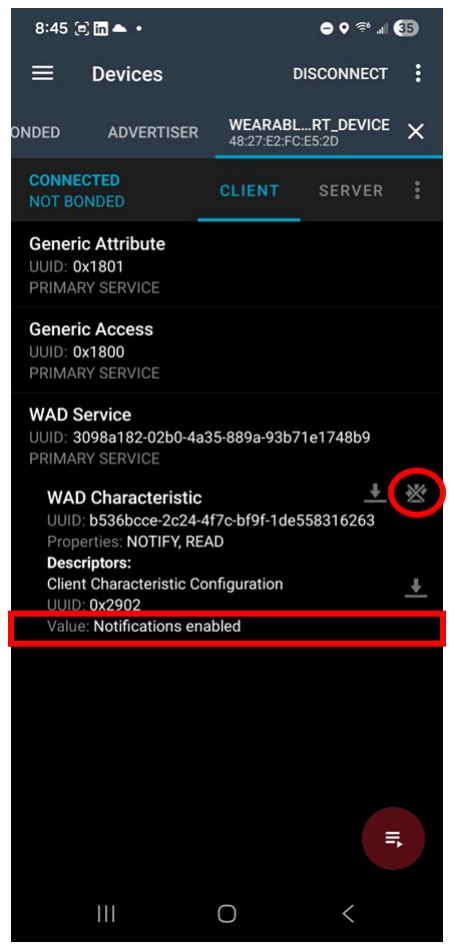
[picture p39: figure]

Figure 8: Screenshot of nRF Connect app showing that automatic notifications have been enabled for WAD data (boxed and circled in red).

7. Under that same “WAD Service” section, there is a subsection called “WAD

Characteristic.” Press and hold that section until it is highlighted, after which a pencil

icon will appear at the top of the app as seen in Figure 9. Select that pencil icon to edit

the format of the data when it is received.

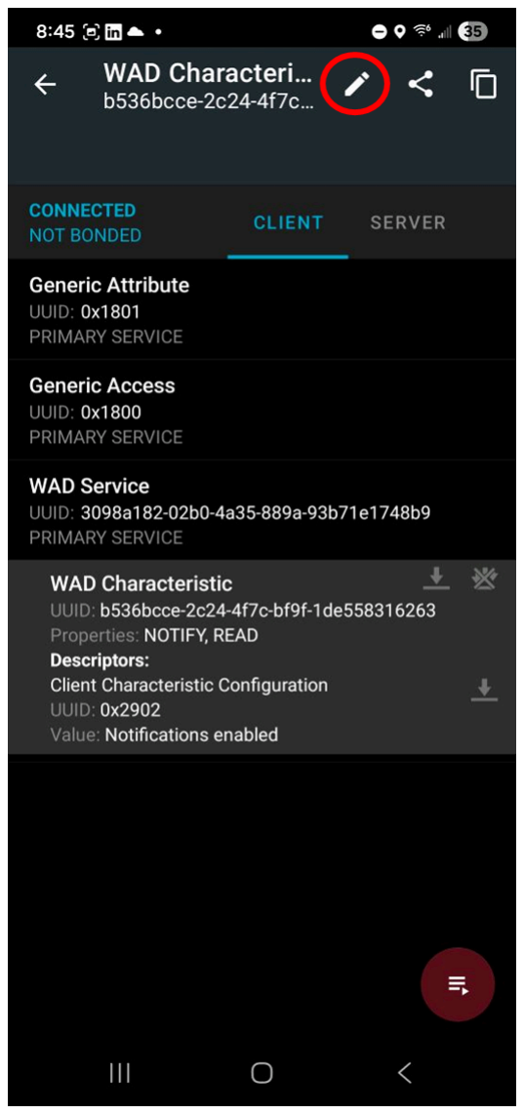
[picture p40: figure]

Figure 9: Screenshot of the “WAD Characteristic” being highlighted in gray and the edit option at the top of the app (circled in red).

8. Once the edit option has been selected, you will see a setting called the “Value Format”

(see Figure 10). Ensure that this setting is set to the “TEXT” option, not the “NO

FORMAT” option. Select “OK” to save this setting.

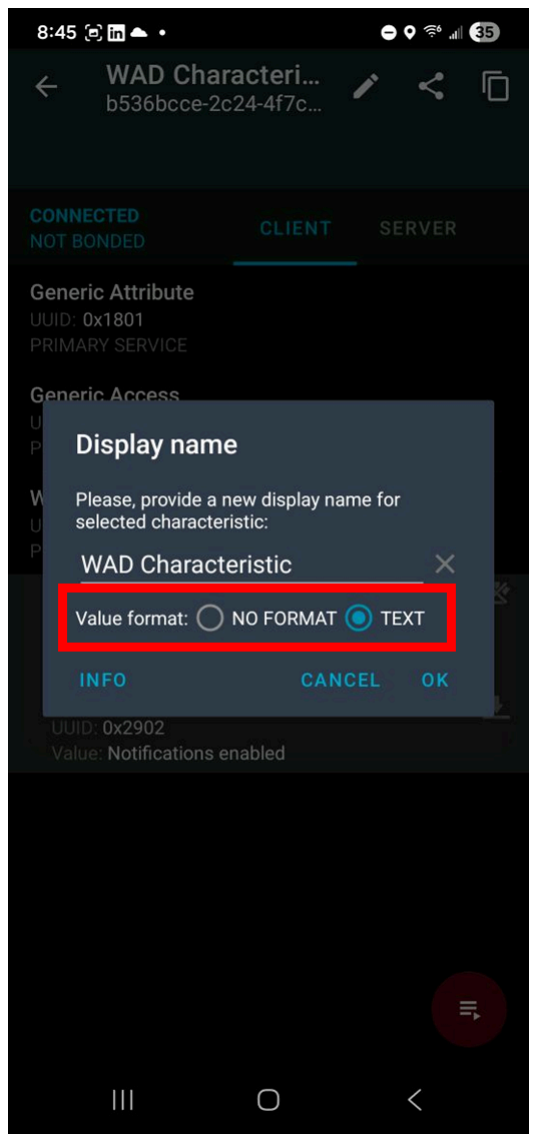
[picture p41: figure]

Figure 10: Screenshot of the Value Format setting set to the “TEXT” option (boxed in red).

9. There is one last setting that needs to be adjusted to properly read the data from the

WAD. Next to the “Client” and “Server” tabs, there is an icon with three dots that

indicates advanced Bluetooth settings (see Figure 11). Select this icon.

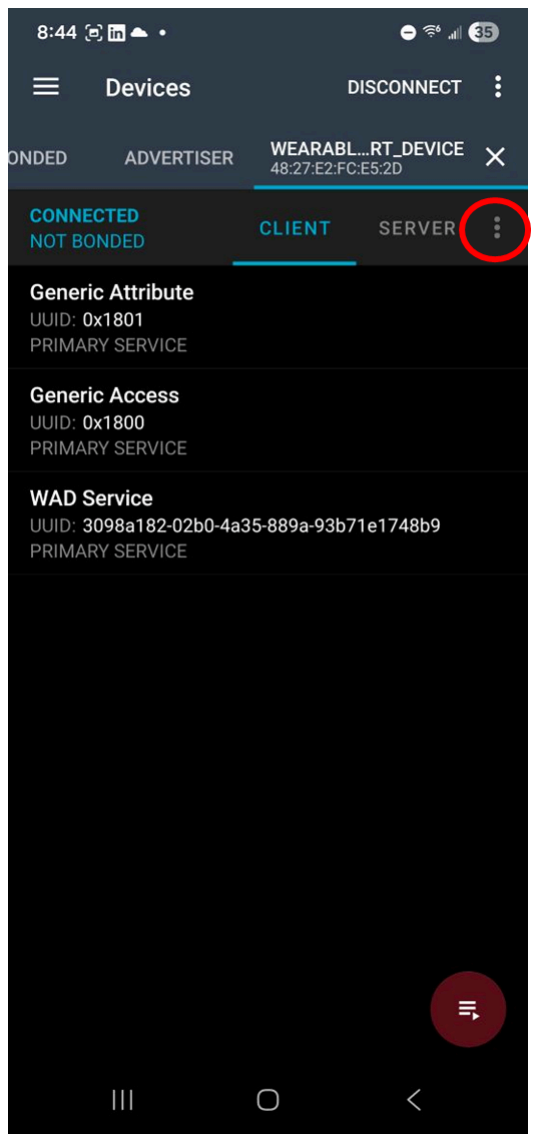
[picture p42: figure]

Figure 11: Screenshot of the Wearable_Alert_Device tab on the nRF Connect app with the advanced Bluetooth settings circled in red.

10. Once the advanced Bluetooth settings have been opened, select the “Request MTU”

option (see Figure 12).

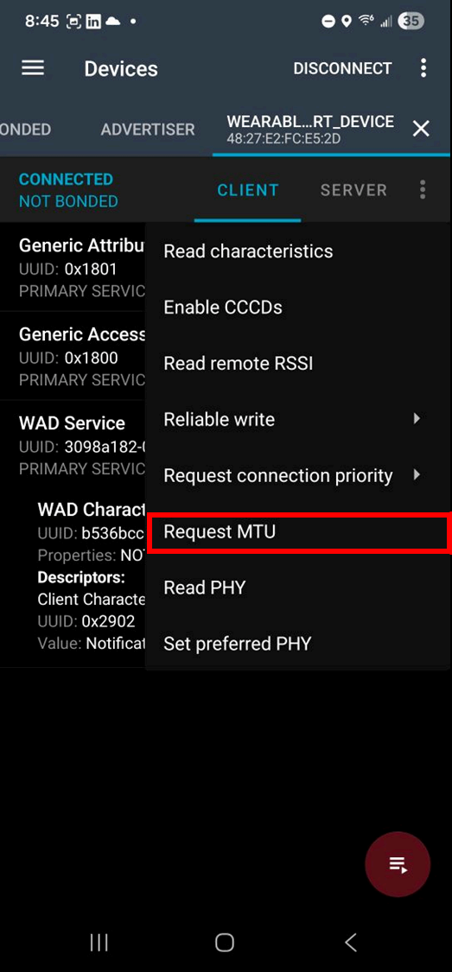
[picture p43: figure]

Figure 12: Screenshot of “Request MTU” option in the advanced Bluetooth settings.

11. Selecting the “Request MTU” option will result in a pop-up window that contains a field

to change the maximum transfer unit (MTU) (see Figure 13). Ensure this field has the

value 517 and select “OK.”

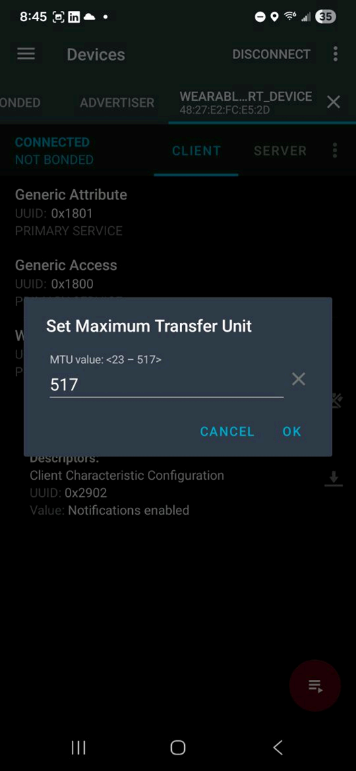
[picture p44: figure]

Figure 13: Screenshot of the field to change the MTU, which is set to the value 517.

Finally, the nRF Connect mobile app has been configured to correctly receive data from a

WAD. What is important to note is that in an ideal mobile app, these steps would not be needed.

These steps are only needed due to the utilization of this specific Bluetooth Serial messaging

app. When the WAD transmits data, either due to the press of its button or by detecting a

gunshot, the data will automatically appear on the nRF Connect mobile app in its raw JSON

format (see Figure 14).

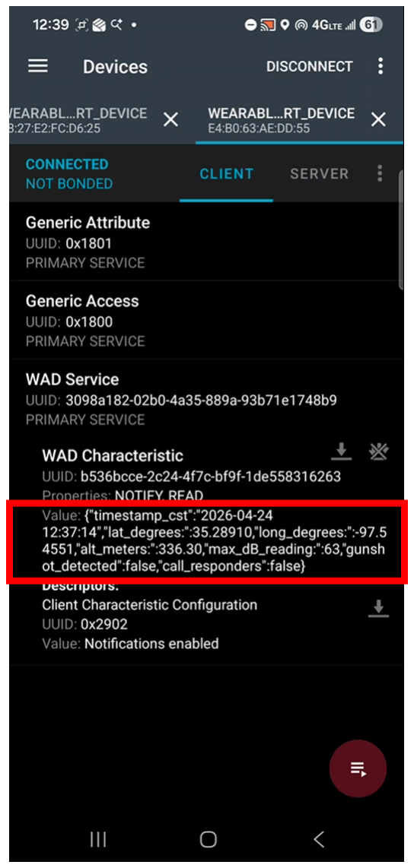
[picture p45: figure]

Figure 14: Screenshot of data from the WAD being received by the nRF Connect mobile app.

Button Operation

The button on the top of the device acts as the main communication between the user and

authorities.

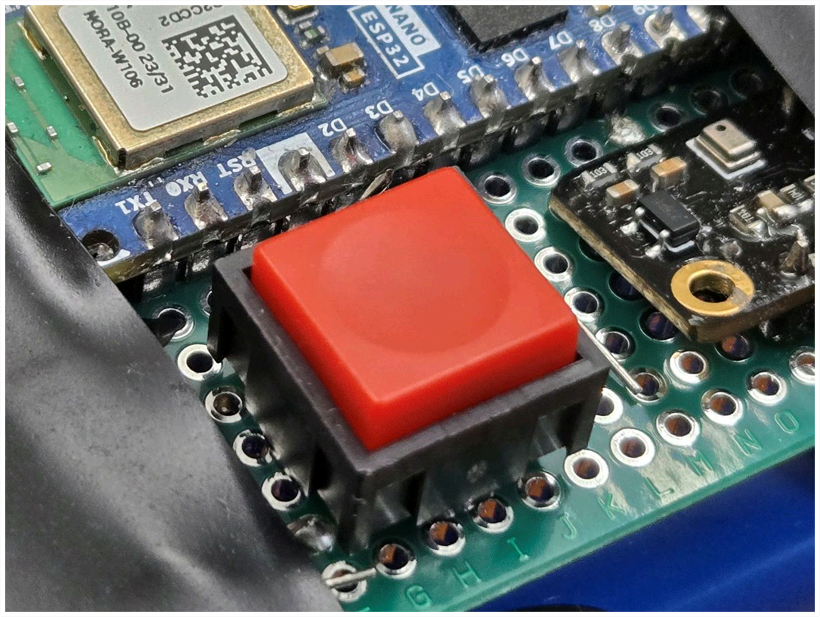
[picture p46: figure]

Figure 15: Button on the top of the WAD

As of right now the button will react with a single press of the button and will update the JSON

file with the data collected such as GPS and gunshot detection. The button itself will send data to

the device if there is a slight holding press. This means that light taps or accidental taps will

rarely set the device off. The button can be pressed in rapid succession and the time stamps and

location will change with each press. As of right now there is no physical or visual indication

that the button has been pressed except for the testing LED on the device, which lights up

whenever the button has been pressed. There is future planning for a slight vibration when the

button is pressed so that the discrete nature of the device is held intact. However, the only

verification methods for a button press are the testing LED and the data being received by the

nRF Connect app from the WAD.

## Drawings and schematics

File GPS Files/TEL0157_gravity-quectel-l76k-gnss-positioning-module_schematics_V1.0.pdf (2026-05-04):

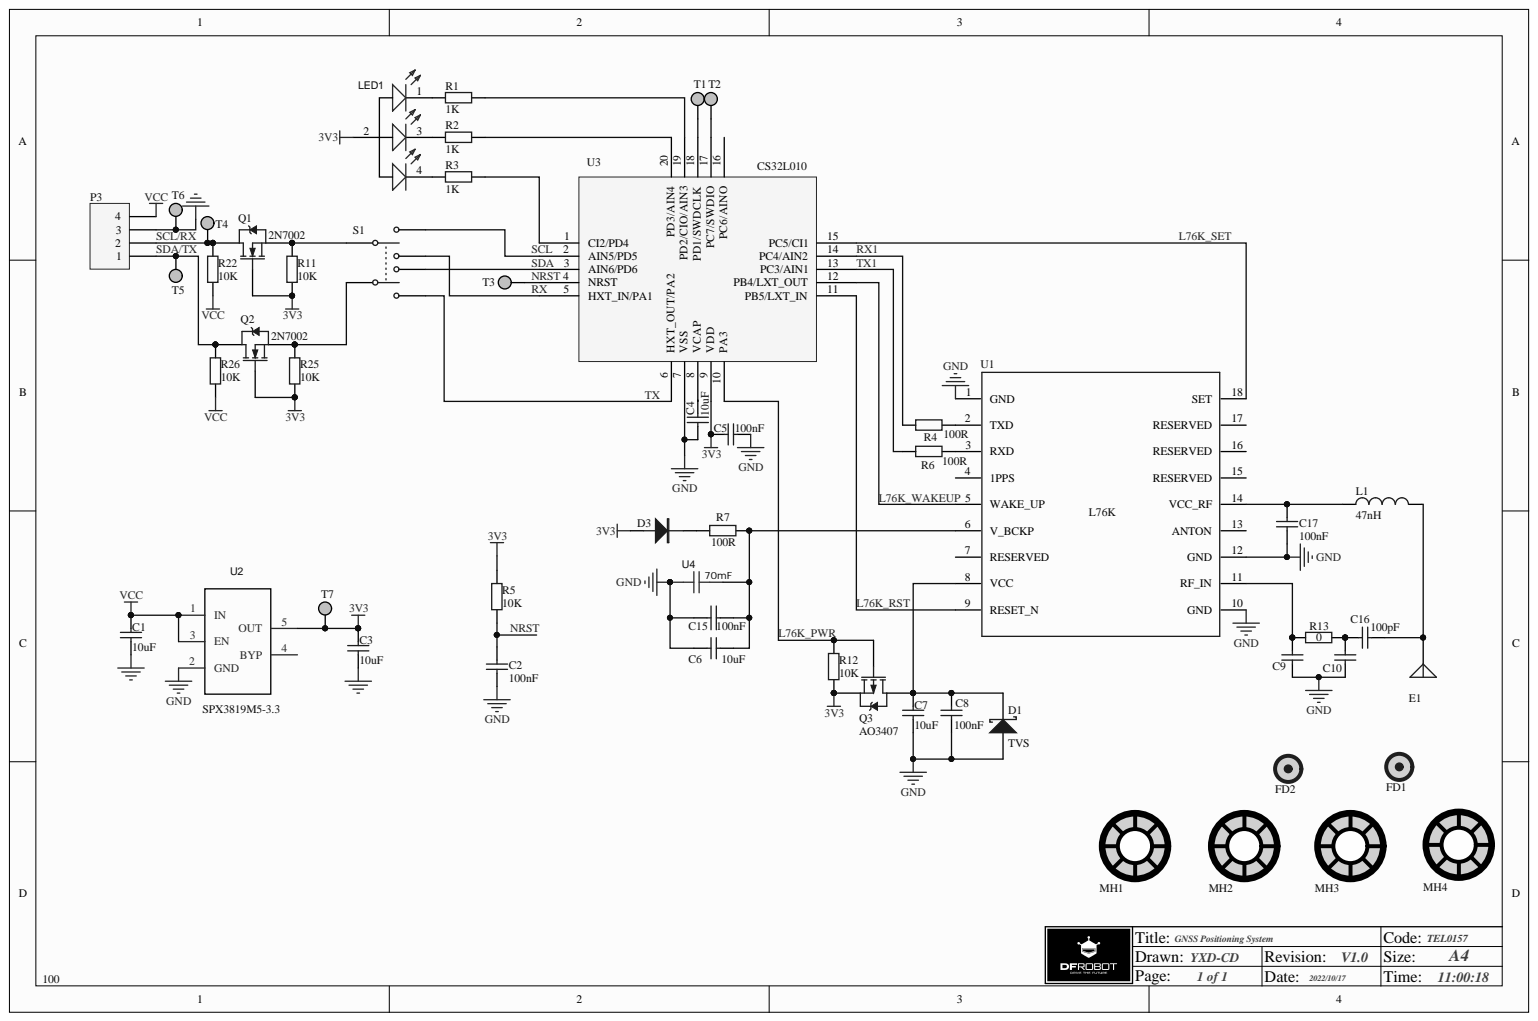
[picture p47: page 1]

15 C⁶/AINO ¹⁶ PC⁷/S

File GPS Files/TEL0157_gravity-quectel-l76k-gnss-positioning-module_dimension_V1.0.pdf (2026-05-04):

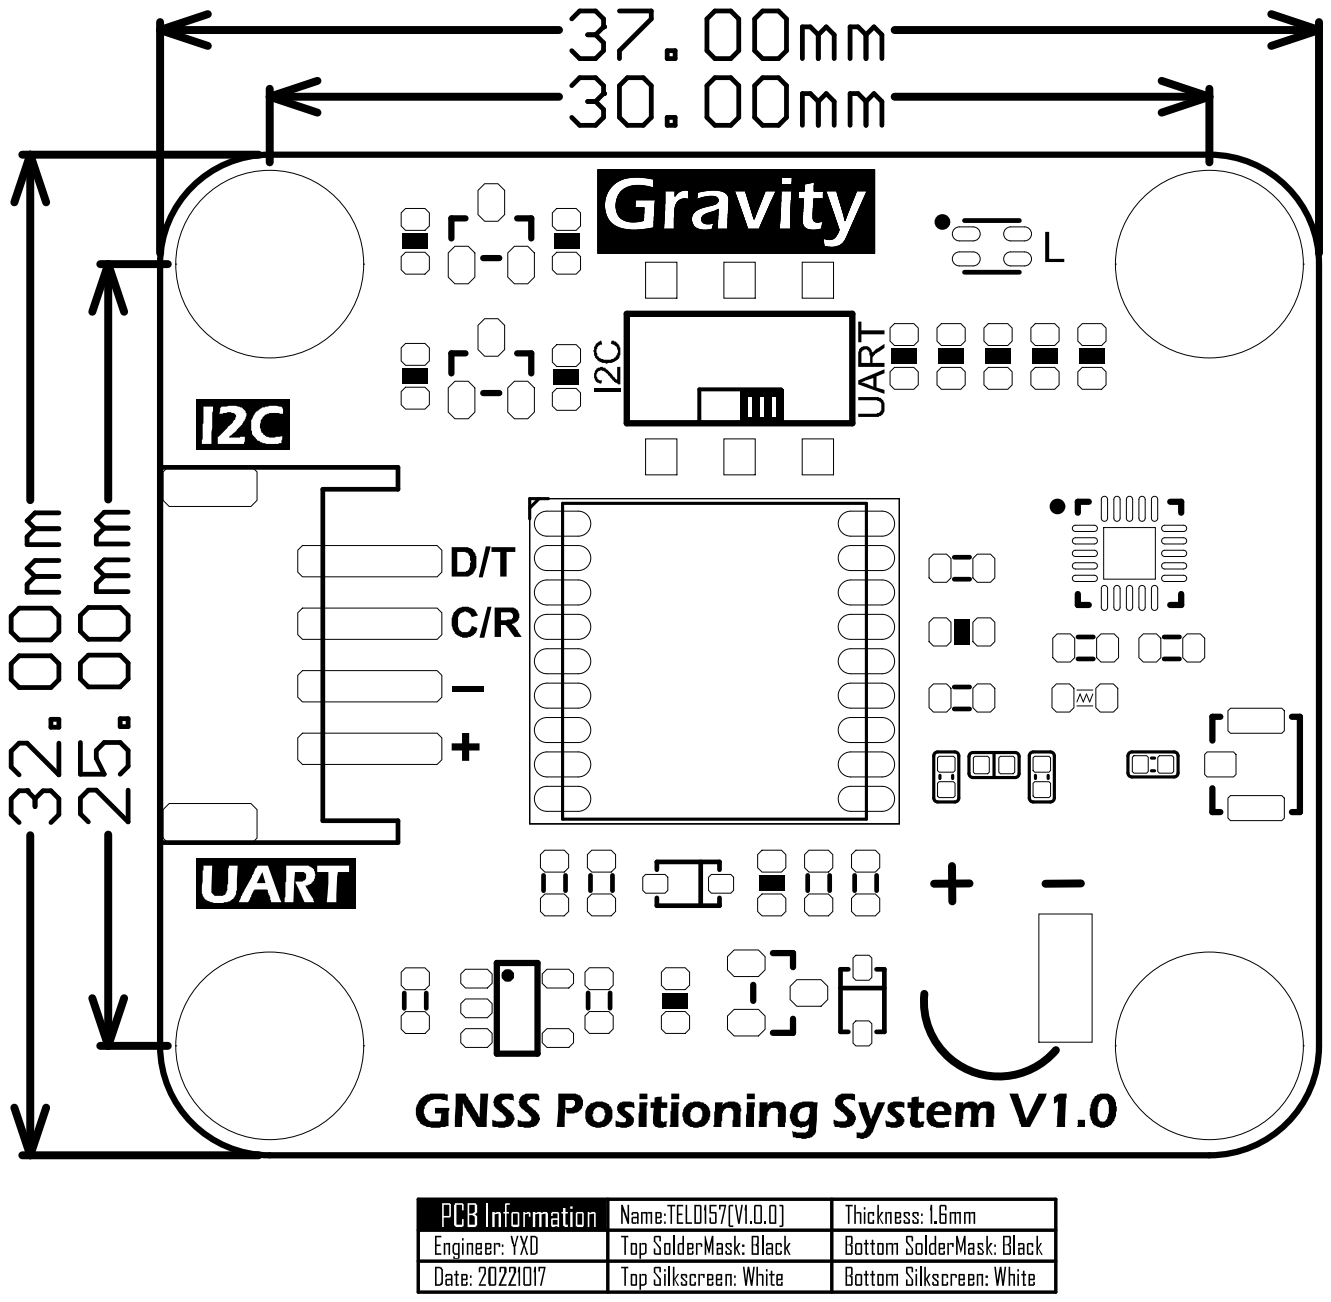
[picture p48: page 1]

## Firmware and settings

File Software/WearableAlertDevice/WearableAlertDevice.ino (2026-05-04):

/*
* Main software file that handles all the functionality
* of the Wearable Alert Device.
*
* @author Alex Ho
* @2026 University of Oklahoma
*/
#pragma once
#include <stdio.h>
#include "config.h"
#include "DFRobot_GNSS.h"
#include "GunshotDetection.h"
#include "WirelessDataTransmission.h"

/*
* Represents a single data packet containing all the 
* information from the GPS module and microphone. 
*
*/
struct DataPacket {
  char timestampCST[20];
  double latDegrees;
  double longDegrees;
  double altitudeM;
  int maxAudioReadingdB;
  bool gunshotDetected;
  volatile bool callEmergencyResponders;
};

DFRobot_GNSS_I2C gpsModule(&Wire, GNSS_DEVICE_ADDR);
int16_t timestamp[6];
DataPacket dataPacket;
AudioCircularBuffer audioBufferV;
AudioCircularBuffer audioBufferdB;
volatile bool isButtonPressed;
bool isReadyToCollectData;
int gpsUpdateCounter;

/*
* Handles the state of the button when it is pressed.
* Button utilizes an interrupt. 
* Function is placed in internal RAM of ESP32, not flash. 
*
*/
void IRAM_ATTR handleButtonInterrupt() {
  // Toggle button state to true when it is pressed.
  isButtonPressed = true;
}

/*
* Adjust the timestamp to be in CST instead of GMT. 
*
*/
void adjustTimestampToCST() {
  timestamp[HOUR_IDX] += OFFSET_FROM_GMT;

  if (timestamp[HOUR_IDX] < 0) {
    // Negative hours, add 24 hours to be within military time range.
    timestamp[HOUR_IDX] += 24;

    // Set the time back one day.
    timestamp[DAY_IDX] -= 1;

    // Check if time went back into previous month.
    if (timestamp[DAY_IDX] == 0) {
      // Time went back into previous month, day is now last day of that month.
      switch (timestamp[MONTH_IDX]) {
        case (1):
          // January, move back to December
          timestamp[DAY_IDX] = 31;
          timestamp[MONTH_IDX] = 12;
          timestamp[YEAR_IDX] -= 1;
          break;
        case (2):
          // February, move back to January
          timestamp[DAY_IDX] = 31;
          timestamp[MONTH_IDX] = 1;
        case (3):
          // March, move back to February
          if ((timestamp[YEAR_IDX] % 4 == 0) && (timestamp[YEAR_IDX] % 100 != 0 || timestamp[YEAR_IDX] % 400 == 0)) {
            // Leap year consideration.
            timestamp[DAY_IDX] = 29;
          }
          else {
            timestamp[DAY_IDX] = 28;
          }
          timestamp[MONTH_IDX] = 2;
          break;
        case (4):
          // April, move back to March
          timestamp[DAY_IDX] = 31;
          timestamp[MONTH_IDX] = 3;
          break;
        case (5):
          // May, move back to April
          timestamp[DAY_IDX] = 30;
          timestamp[MONTH_IDX] = 4;
          break;
        case (6):
          // June, move back to May
          timestamp[DAY_IDX] = 31;
          timestamp[MONTH_IDX] = 5;
          break;
        case (7):
          // July, move back to June
          timestamp[DAY_IDX] = 30;
          timestamp[MONTH_IDX] = 6;
          break;
        case (8):
          // August, move back to July
          timestamp[DAY_IDX] = 31;
          timestamp[MONTH_IDX] = 7;
          break;
        case (9):
          // September, move back to August
          timestamp[DAY_IDX] = 31;
          timestamp[MONTH_IDX] = 8;
          break;
        case (10):
          // October, move back to September
          timestamp[DAY_IDX] = 30;
          timestamp[MONTH_IDX] = 9;
          break;
        case (11):
          // November, move back to October
          timestamp[DAY_IDX] = 31;
          timestamp[MONTH_IDX] = 10;
          break;
        case (12):
          // December, move back to November
          timestamp[DAY_IDX] = 30;
          timestamp[MONTH_IDX] = 11;
          break;
        default:
          break; 
      }
    }
  }
}

// --------------------------------------------
// Main Code
// --------------------------------------------
void setup() {
  Serial.begin(115200);                 // Baud rate set to 115200
  pinMode(BUTTON, INPUT_PULLUP);        // Button is active-low
  pinMode(MIC_PIN, INPUT_PULLDOWN);     // Microphone
  pinMode(LED_PIN, OUTPUT);
  digitalWrite(LED_PIN, LOW);

  // Attach the interrupt function to the active-low button.
  attachInterrupt(digitalPinToInterrupt(BUTTON), handleButtonInterrupt, FALLING);

  isButtonPressed = false;
  isDeviceConnected = false;
  isReadyToCollectData = false;
  dataPacket.gunshotDetected = false;
  dataPacket.callEmergencyResponders = false;
  gpsUpdateCounter = MAX_GPS_UPDATE_COUNTER_VALUE;

  // Initialize wireless data tranmission for Wearable Alert Device.
  initWirelessDataTransmission();

  // GPS Module Initialization
  while(!gpsModule.begin()) {
    Serial.println("Failed to initialize GPS module.");
    delay(1000);
  }
  Serial.println("Successfully initialized GPS module.");
  gpsModule.enablePower();
  gpsModule.setGnss(eGPS_BeiDou_GLONASS);  // Use GPS, Chinese system (Beidou), and Russian satellite system (GLONASS) together. 
  gpsModule.setRgbOn();

  // Set data collection flag to true. 
  isReadyToCollectData = true;
}

void loop() {
  if (isReadyToCollectData) {
    if (gpsUpdateCounter == MAX_GPS_UPDATE_COUNTER_VALUE) {
      // It has been about 1 second since GPS data last updated.
      // Update GPS data.
      // Collect timestamp.
      sTim_t utc = gpsModule.getUTC();
      sTim_t date = gpsModule.getDate();
      timestamp[YEAR_IDX] = date.year;
      timestamp[MONTH_IDX] = date.month;
      timestamp[DAY_IDX] = date.date;
      timestamp[HOUR_IDX] = utc.hour;
      timestamp[MINUTE_IDX] = utc.minute;
      timestamp[SECOND_IDX] = utc.second;

      adjustTimestampToCST();

      // Format timestamp.
      sprintf(dataPacket.timestampCST, "%04d-%02d-%02d %02d:%02d:%02d", timestamp[0], timestamp[1], timestamp[2], timestamp[3], timestamp[4], timestamp[5]);

      // Collect latitude, longitude, and altitude from GPS.
      sLonLat_t latData = gpsModule.getLat();
      sLonLat_t longData = gpsModule.getLon();

      // Northern and Southern Hemisphere checking for coordinates.
      if (latData.latDirection == 'N') {
        // Northern hemisphere, so latitude is positive.
        dataPacket.latDegrees = latData.latitudeDegree;
      }
      else if (latData.latDirection == 'S') {
        // Southern hemisphere, so latitude is negative.
        dataPacket.latDegrees = -1 * latData.latitudeDegree;
      }

      // Eastern and Western Hemisphere checking for coordinates.
      if (longData.lonDirection == 'E') {
        // Eastern hemisphere, so longitude is positive.
        dataPacket.longDegrees = longData.lonitudeDegree;
      }
      else if (longData.lonDirection == 'W'){
        // Western hemisphere, so longituide is negative.
        dataPacket.longDegrees = -1 * longData.lonitudeDegree;
      }

      // Algorithm for averaging altitude measurement for better accuracy.
      dataPacket.altitudeM = 0.0;
      for (int sample = 0; sample < NUM_ALTITUDE_SAMPLES; sample++) {
        dataPacket.altitudeM += gpsModule.getAlt();
      }
      dataPacket.altitudeM /= NUM_ALTITUDE_SAMPLES;

      // Reset update counter.
      gpsUpdateCounter = 0;
    }
    // Collect a new audio sample.
    collectAudioSample(audioBufferV, audioBufferdB);

    // Determine the new max audio reading.
    dataPacket.maxAudioReadingdB = (int)(findMaxDBReading(audioBufferdB));

    //Serial.println(dataPacket.maxAudioReadingdB);

    // Peak Detection.
    if(peakDetection(dataPacket.maxAudioReadingdB)) {
      // dB level spiked above threshold, possible gunshot detected.
      // Perform further analysis to determine if it is actually a gunshot.

      // Clear all values from the frequency data (imaginary values).
      memcpy(frequencyDataImag, zeroArray, NUM_BUFFER_SAMPLES * sizeof(double));

      // Copy raw RMS voltage from audio buffer to the array of frequency data (real values).
      if (audioBufferV.headIdx == 0 && audioBufferV.tailIdx == NUM_BUFFER_SAMPLES - 1) {
        // No array partitions needed, just copy the entire array.
        memcpy(frequencyDataReal, audioBufferV.buffer, NUM_BUFFER_SAMPLES * sizeof(double));
      }
      else if (audioBufferV.tailIdx < audioBufferV.headIdx) {
        // Array partitions needed to properly copy data.
        int firstPartitionSize = NUM_BUFFER_SAMPLES - audioBufferV.headIdx + 1;
        int secondPartitionSize = NUM_BUFFER_SAMPLES - firstPartitionSize;

        memcpy(&frequencyDataReal[0], &audioBufferV.buffer[audioBufferV.headIdx], (firstPartitionSize) * sizeof(double));
        memcpy(&frequencyDataReal[firstPartitionSize - 1], &audioBufferV.buffer[0], (secondPartitionSize) * sizeof(double));
      }
      else if (audioBufferV.headIdx < audioBufferV.tailIdx) {
        // Audio buffer is not entirely full yet.
        int numElements = audioBufferV.tailIdx - audioBufferV.headIdx + 1;
        memcpy(&frequencyDataReal[0], &audioBufferV.buffer[0], (numElements) * sizeof(double));
      }

      // Apply Hamming window function.
      FFT.windowing(FFTWindow::Hamming, FFTDirection::Forward);

      // Compute the Fast Fourier Transform.
      FFT.compute(FFTDirection::Forward);

      // Calculate the magnitudes of the complex numbers in the frequency content.
      FFT.complexToMagnitude();

      // Extract the dominant frequency in Hz.
      double dominantFrequencyHz = FFT.majorPeak();
      
      // Check if dominant frequency is under the threshold frequency for a muzzle blast. 
      if (0.0 < dominantFrequencyHz && dominantFrequencyHz < GUNSHOT_THRESHOLD_HZ) {
        Serial.print("Dominant Frequency: ");
        Serial.println(dominantFrequencyHz, 5);
        dataPacket.gunshotDetected = true;
        dataPacket.callEmergencyResponders = true;
        digitalWrite(LED_PIN, HIGH);
      }
      else {
        dataPacket.gunshotDetected = false;
        dataPacket.callEmergencyResponders = false;
        digitalWrite(LED_PIN, LOW);
      }
    }
    else {
      // Gunshot threshold was not exceeded.
      digitalWrite(LED_PIN, LOW);
    }

    // Format data in JSON format.
    String dataRecord = "{\"timestamp_cst\":\"" + String(dataPacket.timestampCST) + "\"," +
                        "\"lat_degrees:\":" + String(dataPacket.latDegrees, 5) + "," +
                        "\"long_degrees:\":" + String(dataPacket.longDegrees, 5) + "," + 
                        "\"alt_meters:\":" + String(dataPacket.altitudeM, 2) + "," +
                        "\"max_dB_reading:\":" + String(dataPacket.maxAudioReadingdB) + ",";

    if (dataPacket.gunshotDetected) {
      dataRecord += "\"gunshot_detected\":true,"; 
    }
    else {
      dataRecord += "\"gunshot_detected\":false,";
    }

    if (dataPacket.callEmergencyResponders) {
      dataRecord += "\"call_responders\":true}";
    }
    else {
      dataRecord += "\"call_responders\":false}";
    }

    // Send data if button is pressed or gunshot has been detected.
    if ((isButtonPressed || dataPacket.gunshotDetected) && isDeviceConnected) {
      Serial.println("Data Transmitted.");
      dataPacket.callEmergencyResponders = true;
      wadCharacteristic->setValue((unsigned char*)dataRecord.c_str(), dataRecord.length());
      wadCharacteristic->notify();
      isButtonPressed = false;
    }
    dataPacket.callEmergencyResponders = false;

    // Increment GPS update counter.
    gpsUpdateCounter += 1;

    delayMicroseconds((int)((1.0 / SAMPLING_RATE_HZ) * MICROSEC_PER_SEC));
  }
}

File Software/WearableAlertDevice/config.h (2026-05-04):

/*
* Configuration settings for the Wearable Alert Device.
* Note: GPIO numbers are used, not pin numbers.
*
* @author Alex Ho
* @2026 University of Oklahoma
*/

#define BUTTON 17
#define LED_PIN 18
// ----------------------------------
// I2C AND GPS MODULE SETTINGS
// ----------------------------------
#define YEAR_IDX 0
#define MONTH_IDX 1
#define DAY_IDX 2
#define HOUR_IDX 3
#define MINUTE_IDX 4
#define SECOND_IDX 5
#define OFFSET_FROM_GMT -5  // CST is 5 hours behind GMT (no daylight savings)
#define NUM_ALTITUDE_SAMPLES 20
#define MAX_GPS_UPDATE_COUNTER_VALUE 15

// ----------------------------------
// ANALOG MIC SETTINGS
// ----------------------------------
// NOTE: MIC Settings based on Fermion MEMS Microphone (SKU: SEN0487)
#define MIC_PIN 1
#define SAMPLING_RATE_HZ 44100
#define MICROSEC_PER_SEC 1000000
#define MIC_MAX_OUTPUT_V 3.3
#define BIT_RES 4095 // 12-bit resolution = 4096 possible analog readings (0-4095)
#define NUM_PEAK_VOLTAGE_SAMPLES 1000
#define MIC_SENSITIVITY_DBV_PER_PA -42
#define MIC_GAIN 66
#define MIC_DC_BIAS 1.47
#define SOUND_PRESSURE_REF_PA 0.00002
#define NOISE_FLOOR_LEVEL_DB 15
#define NUM_BUFFER_SAMPLES 16
#define GUNSHOT_THRESHOLD_DB 75
#define GUNSHOT_THRESHOLD_HZ 500.0

// Bluetooth
#define SERVICE_UUID "3098A182-02B0-4A35-889A-93B71E1748B9"
#define CHARACTERISTIC_UUID "B536BCCE-2C24-4F7C-BF9F-1DE558316263"
#define BLE_SERVER_NAME "Wearable_Alert_Device"
#define MTU_SIZE 256

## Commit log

2026-04-07 Fix timestamp CST conversion code and negative coordinates
    [WearableAlertDevice.ino, config.h]
2026-04-20 Include Arduino IDE download instructions in README
    Added information about the Arduino IDE for the project.
2026-04-20 Add initial setup instructions for Arduino IDE
    Added initial environment setup instructions for Arduino IDE.
2026-04-20 Enhance README with upload instructions and clarity
    Added a section on verifying and uploading code to a microcontroller and improved clarity in the Arduino Nano ESP32 installation instructions.
2026-04-21 Enhance README with images and detailed instructions
    Added screenshots and clarified instructions for board package installation, pin numbering settings, and library dependencies in the README.
2026-04-22 Enhance README with software file descriptions
    Added descriptions for software files related to the Wearable Alert Device project, including details on functionality and configuration.
2026-04-22 Added frequency code and LED code
2026-04-23 Move Old Schematics to different folder
    [Wearable_Alert_Device.kicad_pcb, Wearable_Alert_Device.kicad_sch, Wearable_Alert_Device_Wiring.kicad_pcb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]
2026-04-23 Final Schematics and Wiring Diagram
    [WearableAlertDevice_Final.kicad_pcb, WearableAlertDevice_Final.kicad_sch, WearableAlertDevice_Wiring_Diagram_Final.kicad_pcb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]
2026-04-23 Old Designs
    [Microphone_System.kicad_pcb, Microphone_System.kicad_sch, Microphone_System_Wiring.kicad_pcb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]
2026-04-23 KiCad Symbols
2026-04-23 Move Schematics to KiCad Folder
    [Microphone_System.kicad_pcb, Microphone_System.kicad_sch, Microphone_System_Wiring.kicad_pcb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]
2026-04-28 Add files via upload
    All current WAR's as of 4/27
2026-04-29 Change Symbol for Lipo Charger
    [WearableAlertDevice_Final.kicad_sch, WearableAlertDevice_Wiring_Diagram_Final.kicad_sch]
2026-04-29 Updated Lipo Charger Symbol
2026-05-01 Updated GPS Name
    [WearableAlertDevice_Final.kicad_sch, WearableAlertDevice_Wiring_Diagram_Final.kicad_sch]
2026-05-01 Change File Name
    [Capstone Design.kicad_sch]
2026-05-04 Add files via upload
    All files required to recreate the case around the WAD
    [Box Cap.stl, Box Right Top Half.obj, Box Right Top Half.stl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]
2026-05-04 Add LED_PIN definition to config.h
2026-05-04 Implement LED feedback for gunshot detection
    Added LED control for gunshot detection indication.
2026-05-04 Add Team Names, Date, and Project name
    [WearableAlertDevice_Final.kicad_sch, WearableAlertDevice_Wiring_Diagram_Final.kicad_sch]
